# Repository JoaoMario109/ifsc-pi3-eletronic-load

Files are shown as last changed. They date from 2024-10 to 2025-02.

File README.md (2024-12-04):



<!-- PROJECT LOGO -->
<br />
<div align="center">
  <a href="https://github.com/JoaoMario109/ifsc-pi3-eletronic-load">
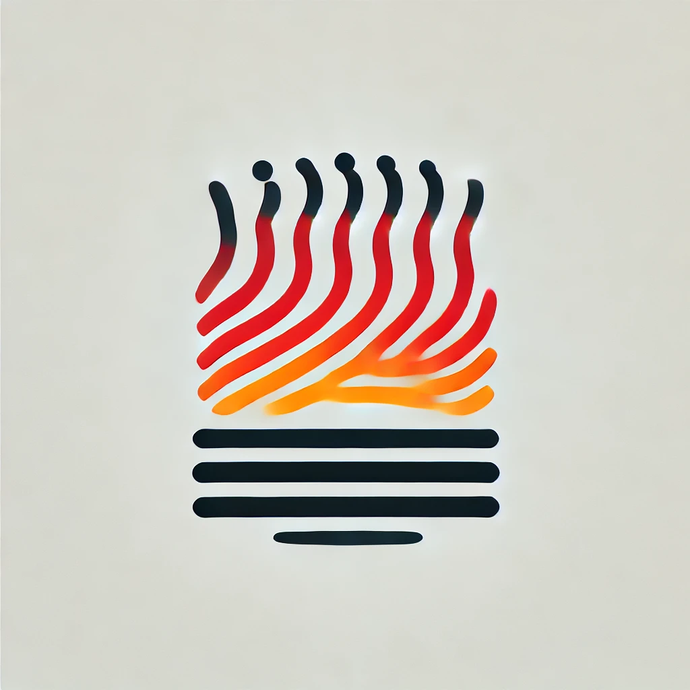
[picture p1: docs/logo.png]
Project Logo
    
  </a>

  <h3 align="center">Simple Electronic Load</h3>

  <p align="center">
    <br />
    <br />
    <a href="https://github.com/JoaoMario109/ifsc-pi3-eletronic-load/issues">Report Bug</a>
    ·
    <a href="https://github.com/JoaoMario109/ifsc-pi3-eletronic-load/issues">Request Feature</a>
  </p>
</div>

<!-- TABLE OF CONTENTS -->
<details>
  <summary>Table of Contents</summary>
  <ol>
    <li>
      <a href="#about-the-project">About The Project</a>
      <ul>
        <li><a href="#about-the-project-overview">Overview</a></li>
      </ul>
    </li>
    <li>
      <a href="#license">License</a>
    </li>
    <li>
      <a href="#contact">Contacts</a>
    </li>
  </ol>
</details>

<!-- ABOUT THE PROJECT -->

## About The Project

This project is the implementation of a simple electronic load with WiFi integration and the ability to operate using custom waveforms. It forms part of (PI3) for the Electronics Engineering course at IFSC, Campus Florianópolis.

### Overview

The electronic load is designed to handle up to 100W of power and supports four different operating modes: constant current, constant power, constant resistance, and constant voltage. Additionally, it can execute custom waveforms uploaded via its various communication interfaces.

The load is divided into three key modules:
1. **Power Module** – Contains the hardware components responsible for handling the load, such as the power transistors and other essential elements.
2. **Control Module** – Manages the desired operating mode and ensures the system maintains the appropriate levels of current, voltage, or resistance.
3. **Communication Module** – Facilitates interaction between the user and the device via WiFi, USB, or other interfaces, and stores custom waveforms on an SD card for future use.

The device can be accessed through its control panel, WiFi, or USB interface, and its communication capabilities can easily be expanded. Any compatible interface can be connected to the main I2C bus using an SCPI-like protocol.

<p align="right">(<a href="#top">back to top</a>)</p>

<!-- LICENSE -->

## License

Distributed under the MIT License. See [LICENSE](LICENSE) for more information.

<p align="right">(<a href="#top">back to top</a>)</p>

<hr />

<!-- CONTACT -->

## Contact

Alejo Perdomo Milar [alejo.pm@aluno.ifsc.edu.br](alejo.pm@aluno.ifsc.edu.br)\
João Mário Carnieletto Izoton Lago [joao.mcil2003@aluno.ifsc.edu.br](joao.mcil2003@aluno.ifsc.edu.br)\
Paulo Cezar Ventura Junior [paulo.cvj@aluno.ifsc.edu.br](paulo.cvj@aluno.ifsc.edu.br)

Project Link: [https://github.com/JoaoMario109/ifsc-pi3-eletronic-load](https://github.com/JoaoMario109/ifsc-pi3-eletronic-load)

<p align="right">(<a href="#top">back to top</a>)</p>

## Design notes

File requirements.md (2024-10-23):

| **Absolute Maximum Values** | **Maximum Value** | **Unit** |
| --- | --- | --- |
| **Maximum Power** | 100 | W |
| **Maximum Current** | 10 | A |
| **Maximum Voltage** | 70 | V |
| **Maximum Temperature** | 100 | °C |

| **Control Parameters** | **Range** | **Unit** |
| --- | --- | --- |
| **Constant Power** | 0.1 ~ 100¹ | W |
| **Constant Current** | 0.2 ~ 10 | A |
| **Constant Voltage** | 2 ~ 70 | V |
| **Constant Resistance** | 3 ~ 500¹ | Ω |
| **Update Frequency** | 2 | Hz |
| **Current Resolution** | 0.1 | A |
| **Voltage Resolution** | 0.1 | V |
| **Over Power Protection** | 100 | W |
| **Over Voltage Protection** | 70 | V |
| **Over Current Protection** | 10 | A |
| **Over Temperature Protection** | 90 | °C |

¹ Depends on the input voltage and current.

| **Communication Protocols** | **Interface** |
| --- | --- |
| WebSocket | WiFi |
| SD card | SD card |
| I²C | Wired connection |

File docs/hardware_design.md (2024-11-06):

# Seção Analógica

## Correção de Offset

Os diodos na seção de correção de offset têm a função de compensar o fato de que o amplificador LM324 não é do tipo rail-to-rail, ou seja, ele não consegue atingir os 12V necessários para despolarizar completamente o transistor PNP Q2. Assim, foram utilizados diodos em série para que a queda de tensão neles crie um offset no emissor, garantindo uma operação correta.

## Controle Analógico

O controle analógico da carga eletrônica é composto por duas etapas principais:

### 1. Inversor de Sinal

Esta etapa consiste em um inversor para compensar o fato de que o driver com transistor PNP inverte o sinal. Pela natureza do circuito, com 12V não haverá passagem de corrente pelo transistor PNP, enquanto com 0V haverá a corrente máxima. Após a inversão, com 0V não haverá corrente, e o aumento da corrente será proporcional à tensão de entrada.

### 2. Controlador PID Analógico

A segunda etapa é um controlador PID analógico feito com um amplificador operacional (ampop). Esse controlador é interessante porque, caso seja necessário desativá-lo para utilizar apenas o controle digital, basta colocar um curto em R14 e C6.

O cálculo do controlador foi feito através de um método empírico de sucessivas aproximações, onde, utilizando o LTSpice, foram ajustados os valores de capacitância e resistência até atingir o comportamento desejado. É importante ressaltar que sempre há uma diferença entre simulação e prática; portanto, quando implementado em bancada, será realizado um ajuste fino dos componentes.

| Componente | Descrição |
|---|---|
| **Capacitor C3** | Aumentar a capacitância de C3 reduz o tempo de subida (rise time), mas também aumenta o fenômeno de ringing. |
| **Resistor R10** | Reduzir a resistência de R10 aumenta a velocidade do circuito, mas também eleva o ringing. |
| **Capacitor C6** | Controla a velocidade de resposta do controlador. Quanto maior a capacitância, mais lenta será a resposta. |

Os resistores em série com os capacitores têm uma função equivalente à variação direta da capacitância dos capacitores associados.

### Valores Encontrados

| Componente | Valor |
|---|---|
| R14 | 330Ω |
| C6 | 10nF |
| R10 | 720Ω |
| C3 | 100nF |
| R13 | 5kΩ |
| R11 | 1kΩ |

### Simulação

<div style="text-align: center;">
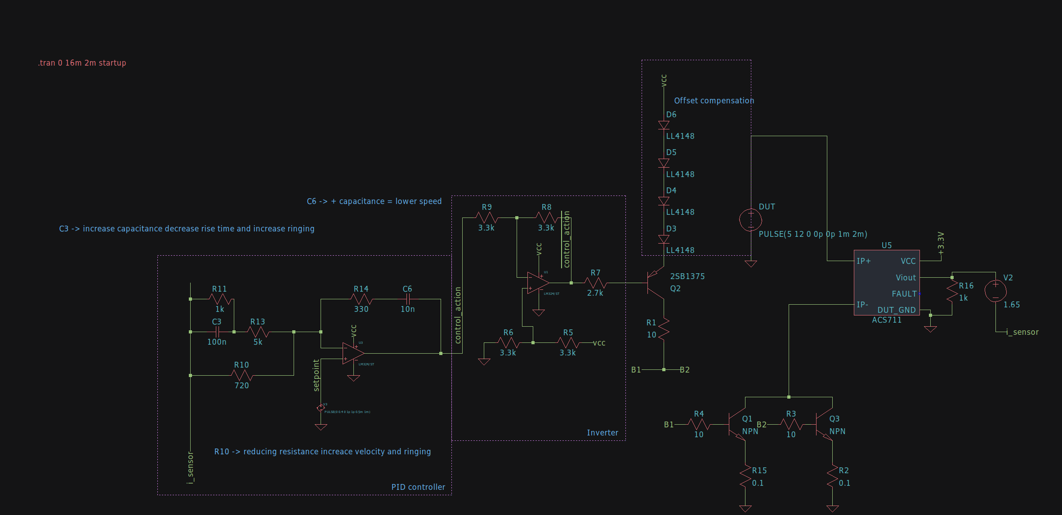
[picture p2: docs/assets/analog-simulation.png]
Simulação do Controlador PID Analógico
	
</div>

<div style="text-align: center;">
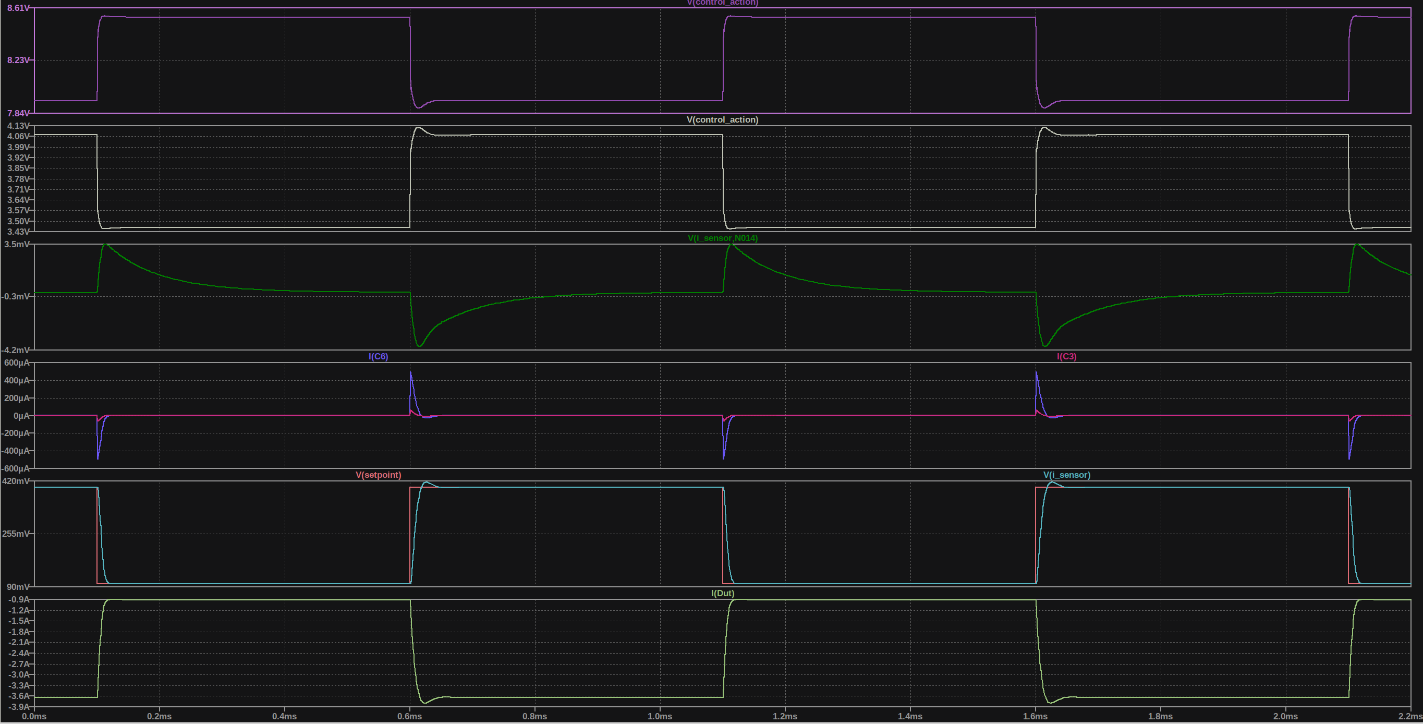
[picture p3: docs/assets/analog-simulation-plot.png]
Simulação do Controlador PID Analógico Plot
	
</div>

### Observações

A resposta do controlador PID analógico é satisfatória para o projeto, tendo um leve overshoot e settling time aceitável. Ainda assim, é importante ressaltar que a implementação prática pode apresentar diferenças em relação à simulação, e ajustes finos podem ser necessários.

---

## Sensor de Tensão

A configuração do sensor de tensão consiste em um divisor de tensão simétrico com redução de modo comum, conectado a um amplificador operacional em modo diferencial.

### Divisor de Tensão

O divisor de tensão é composto por três etapas acopladas:

1. **Divisor de Tensão de Modo Comum**: Resistores conectados ao GND, em conjunto com resistores em série com a entrada, atuam como divisor de tensão para o modo comum.
2. **Divisor de Tensão Diferencial**: Um resistor que conecta os resistores do divisor em série com a entrada funciona como um divisor diferencial, configurado de forma simétrica para maximizar a redução de ruído.

Para o cálculo dos valores desses divisores, foi utilizado o método empírico de sucessivas aproximações.

### Amplificador Operacional em Modo Diferencial

O amplificador operacional diferencial é usado nesta configuração porque a entrada terá um offset de tensão devido às quedas de tensão nos fios e trilhas. O ganho foi ajustado para que, com uma entrada de 120V no divisor de tensão, a saída forneça 3.3V, aproveitando todo o range do ADC.

### Filtros

Existem três etapas de filtro passa-baixa no circuito:

- **Entrada (2 filtros)**: Reduzem o ruído de modo comum e diferencial.
- **Saída (1 filtro)**: Reduz o ruído de saída do amplificador operacional.

Todos os filtros foram calculados para ter uma frequência de corte aproximada de 1kHz.

### Proteções

O circuito conta com proteções contra sobretensão e tensão reversa, tanto na entrada quanto na saída. A proteção de sobretensão é feita por diodos TVS.

### Valores Encontrados

| Componente | Valor |
|---|---|
| R5, R6 | 50kΩ |
| R7, R8, R9 | 1kΩ |
| C2, C4 | 100nF |
| C3 | 10nF |
| R10 | 500Ω |
| C1 | 1uF |

### Simulação

<div style="text-align: center;">
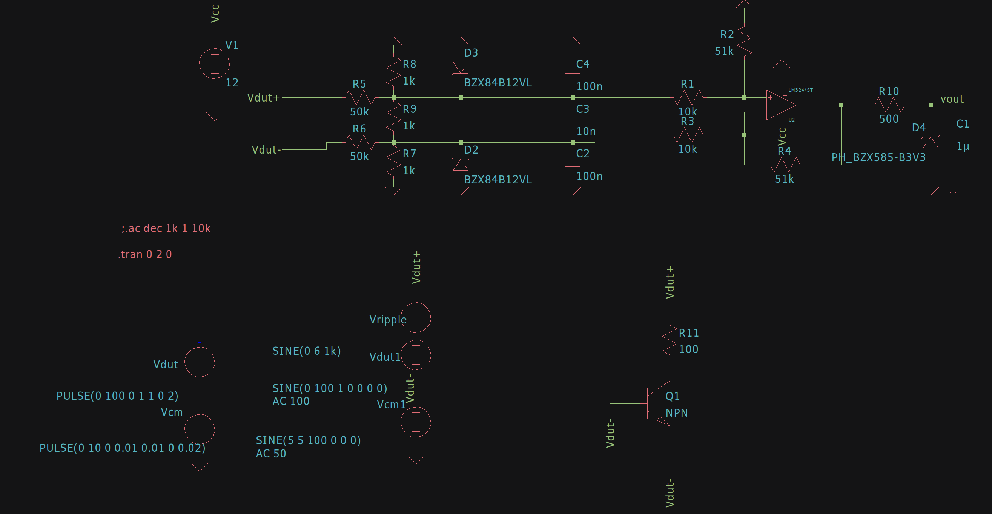
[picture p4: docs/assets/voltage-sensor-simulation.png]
Simulação do Sensor de Tensão
	
</div>

<div style="text-align: center;">
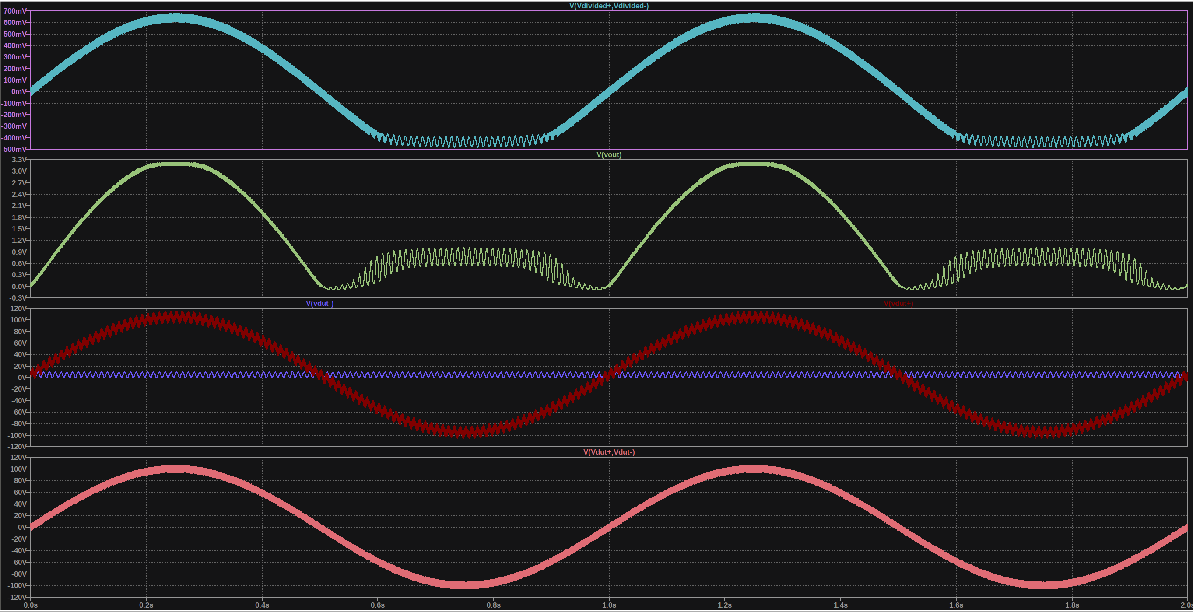
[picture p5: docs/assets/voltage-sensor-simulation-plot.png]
Simulação do Sensor de Tensão Plot
	
</div>

---

# Seção de Potência

## Polarização do Transistor de Potência e Driver

Para determinar os valores dos resistores de base dos transistores de potência, foi utilizado o método de sucessivas aproximações, buscando um ponto de operação onde o transistor tenha corrente de base suficiente para entrar em saturação.

### Valores Encontrados

| Componente | Valor |
|---|---|
| Resistor da base | 20Ω |
| Resistor da base do driver | 2.2kΩ |
| Resistor do emissor | 0.1Ω  |

---

## Cálculo da Resistência Térmica Máxima do Dissipador

Para determinar a resistência térmica máxima do dissipador necessário para dissipar uma potência total de 100W distribuída entre dois transistores, com aplicação direta de pasta térmica, foram consideradas as seguintes especificações:

| Especificação | Valor |
|---|---|
| Resistência térmica junction-to-case (Rθjc) | 1.25 °C/W |
| Temperatura ambiente máxima | 30 °C |
| Temperatura máxima de operação | 120 °C |

### Cálculo

1. **Cálculo do aumento de temperatura permitido ($\Delta T$)**:
   $$
   \Delta T = T_{max} - T_{amb} = 120 \,°C - 30 \,°C = 90 \,°C
   $$

2. **Distribuição da Potência**: Cada transistor dissipará 50W.

3. **Resistência Térmica Junction-to-Case Total**:
   $$
   R_{\theta jc} \times P = 1.25 \,°C/W \times 50 \,W = 62.5 \,°C
   $$

4. **Resistência Térmica Necessária para o Dissipador ($R_{\theta sa}$)**:
   $$
   R_{\theta sa} = \frac{\Delta T - (R_{\theta jc} \times P)}{P_{total}} = \frac{27.5 \,°C}{100 \,W} = 0.275 \,°C/W
   $$

Portanto, para manter a temperatura dos transistores abaixo de 120 °C, a resistência térmica máxima do dissipador deve ser **0.275 °C/W**.

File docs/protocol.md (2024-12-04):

# SCPI-like Protocol

## I2C Bus Overview

Devices controlling the load must connect to the load's I2C bus to send commands. The protocol supports hierarchical parsing with registers and sub-registers to interact with the load server and HMI server.

### I2C Addresses

- **Load Server:** 0xA  
  Responsible for managing active control of power and analog systems. This runs on the STM32 in the load module.  
- **HMI Server:** 0x5  
  Manages operations on the SD card, load configuration, and streaming functionalities. This runs on the ESP32 in the front panel.

---

## Protocol Specifications for I2C Communication

### Command Format

The protocol uses a structured command format, represented as:  
**C:R:S:VV**  

- **C:** Command type (0x0 for query, 0x1 for set)
- **R:** Register (defines the resource or mode being accessed)
- **S:** Sub-register (specific sub-resource or parameter)
- **VV:** Value (2 bytes, applicable for set operations)

### Supported Commands

#### Identification (ID)
- **Query ID**:  
  Command: `0x0:0x0:0x0`  
  Returns the identification string of the load module.  

#### Input Control (IN)
- **Disable Input**:  
  Command: `0x1:0x1:0x0:0x0`  
  Disables the input (output terminals).  
- **Enable Input**:  
  Command: `0x1:0x1:0x0:0x1`  
  Enables the input (output terminals).  
- **Query Input State**:  
  Command: `0x0:0x1:0x0`  
  Returns whether the input is currently enabled or disabled.  

#### Operating Modes (MD)
- **Query Mode**:  
  Command: `0x0:0x2:0x0`  
  Returns the currently selected operating mode.  
- **Set Mode to Constant Current (CC)**:  
  Command: `0x1:0x2:0x1`  
- **Set Mode to Constant Voltage (CV)**:  
  Command: `0x1:0x2:0x2`  
- **Set Mode to Constant Resistance (CR)**:  
  Command: `0x1:0x2:0x3`  
- **Set Mode to Constant Power (CP)**:  
  Command: `0x1:0x2:0x4`  

#### Levels (LV)
- **Query Level**:  
  Command: `0x0:0x3`  
  Queries the current level for the specified sub-register.  
- **Set Current Level**:  
  Command: `0x1:0x3:0x1:VV` (Value in amperes)  
- **Set Voltage Level**:  
  Command: `0x1:0x3:0x2:VV` (Value in volts)  
- **Set Resistance Level**:  
  Command: `0x1:0x3:0x3:VV` (Value in ohms)  
- **Set Power Level**:  
  Command: `0x1:0x3:0x4:VV` (Value in watts)  

#### Status (ST)
- **Query Status**:  
  Command: `0x0:0x4:0x0`  
  Returns a structured response with the following fields:  
  - **Byte 1:** Input state (0 or 1)  
  - **Byte 2:** Current mode (CC, CV, CR, CP)  
  - **Bytes 3-4:** Current set current value  
  - **Bytes 5-6:** Current set voltage value  
  - **Bytes 7-8:** Current set resistance value  
  - **Bytes 9-10:** Current set power value  
  - **Bytes 11-12:** Measured current value  
  - **Bytes 13-14:** Measured voltage value  

### Commands
| Command |  Value | Description |
|---|---|---|
| Query | 0x0 | Query the value of a register |
| Set | 0x1 | Set the value of a register |

### Registers

| Mode | Register | Description |
|---|---|---|
| ID  | 0x0 | Constant Current |
| IN  | 0x1 | Input |
| MD  | 0x2 | Mode |
| LV  | 0x3 | Levels |
| ST  | 0x4 | Status |

### Sub-Registers

| Mode | Sub-Register | Description |
|---|---|---|
| __  | 0x0 | General |
| CC  | 0x0 | Current |
| CV  | 0x1 | Voltage |
| CR  | 0x2 | Resistance |
| CP  | 0x3 | Power |

## HMI Protocol (HMI Server)

### Resource Codes

- **ID** Identification
- **LK** Panel Locking
- **ST** Streamer module
- **CX** Set File Descriptor
- **LS** SD Read Operation
- **WT** SD Write Operation

### Identification

- **ID?** Queries the panel module for its identification string.

### Panel Locking

- **LK?** Queries whether the front panel is currently locked (user interaction disabled) or unlocked (user interaction enabled).
- **LK 0** Unlocks the front panel, preventing user interaction.
- **LK 1** Locks the front panel, allowing user interaction.

### SD Card File Operations

#### Listing available files

- **LS 0** Queries files in SD card `streams` directory from page zero, each page contains 10 files.

#### Selecting a file descriptor

- **CX?** Queries the current file descriptor.
- **CX <name 20 chars>.st** Sets the file descriptor to the specified file. The file descriptor is used in subsequent operations to refer to the file.
- **CX 0** Resets the file descriptor to zero.

#### Write operations (Set file descriptor before writing, if file descriptor does not exist, it will be created)

- **WT** This will clean current file in file descriptor.
- **WT <cmd>** This will write the data to the file in file descriptor, data can be any of valid commands in protocol.

#### Streamer module

- **ST?** Will return 1 if streamer module is streaming data, 0 otherwise.
- **ST 0** Will stop the streamer module.
- **ST 1** Will start the streamer module using the file descriptor as the source.

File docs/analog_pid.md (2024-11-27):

## Ajuste do Controlador Analógico

Para realizar o ajuste (tuning) do controlador analógico, foram colocados dois trimpots nos resistores R13 e R10, conforme mostrado na figura abaixo:

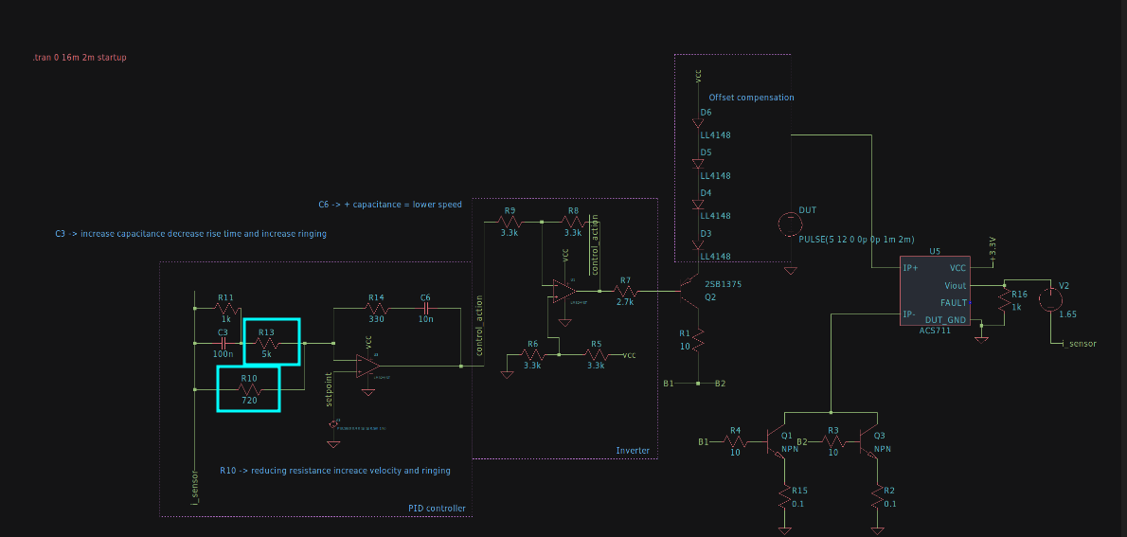
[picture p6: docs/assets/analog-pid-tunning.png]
Ajuste PID Analógico


O valor de R10 foi ajustado inicialmente para obter a resposta mais rápida possível com uma leve oscilação. Em seguida, o valor de R13 foi modificado para reduzir essa oscilação.

### Respostas do Controlador no Osciloscópio

Abaixo estão algumas capturas do osciloscópio mostrando a resposta do controlador analógico com diferentes ajustes dos trimpots:

- Resposta com tempo de subida rápido mas com maior oscilação:
  
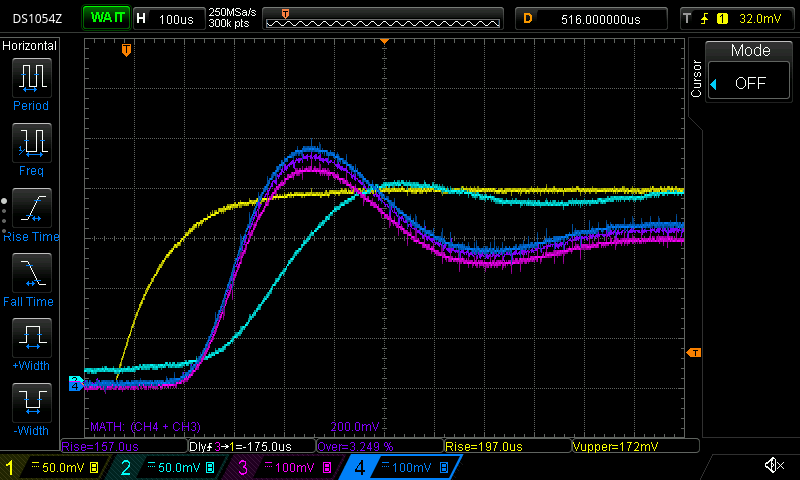
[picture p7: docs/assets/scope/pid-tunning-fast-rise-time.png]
Osciloscópio PID Rápido
  

- Resposta com tempo de subida médio e oscilação moderada:
  
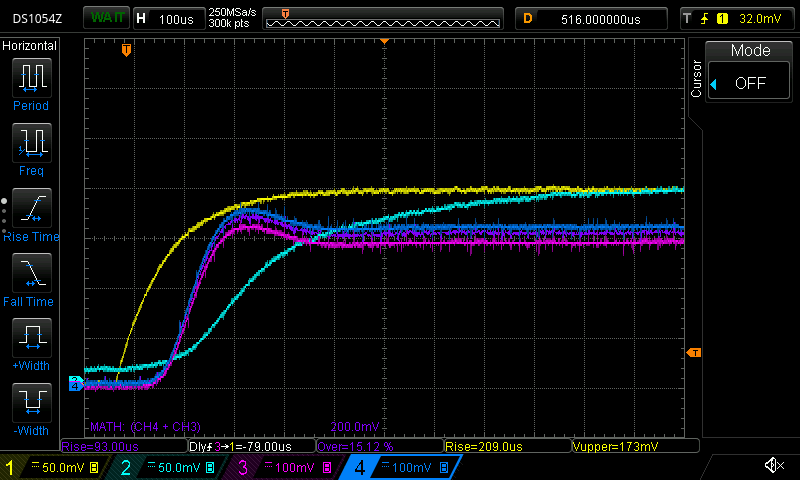
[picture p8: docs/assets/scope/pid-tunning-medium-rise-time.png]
Osciloscópio PID Médio
  

- Resposta com tempo de subida lento e oscilação mínima:
  
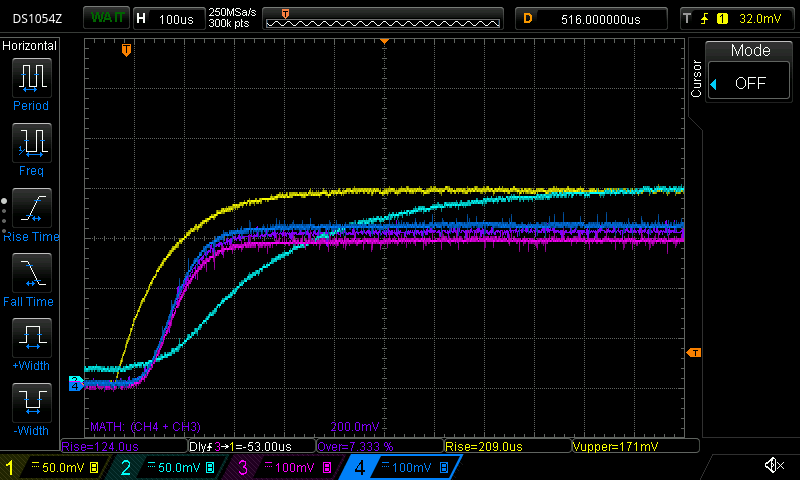
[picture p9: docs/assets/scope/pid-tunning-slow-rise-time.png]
Osciloscópio PID Lento
  

**Legenda dos canais no osciloscópio:**
- Canal amarelo: setpoint
- Canal azul claro: saída do sensor de corrente
- Canal azul escuro e roxo: corrente em cada transistor

A melhor resposta foi obtida com os valores de **R10 = 2k7** e **R13 = 250R**, resultando em um atraso de resposta de 97 µs e um tempo de subida de 111 µs, significativamente mais rápido que o desejado (2 Hz).

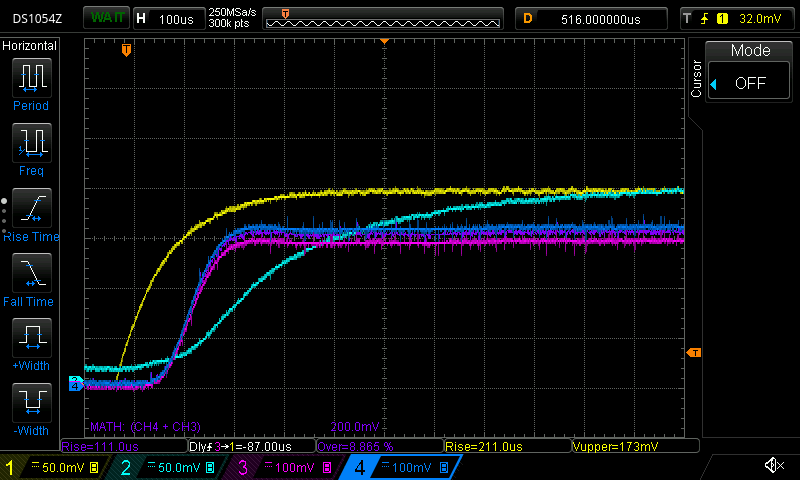
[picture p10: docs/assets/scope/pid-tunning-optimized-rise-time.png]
Osciloscópio PID Otimizado


### Resposta do Controlador em Condições de Estresse

Abaixo estão as capturas do osciloscópio com o controlador analógico sob estresse, usando a frequência máxima do DAC para gerar o setpoint.

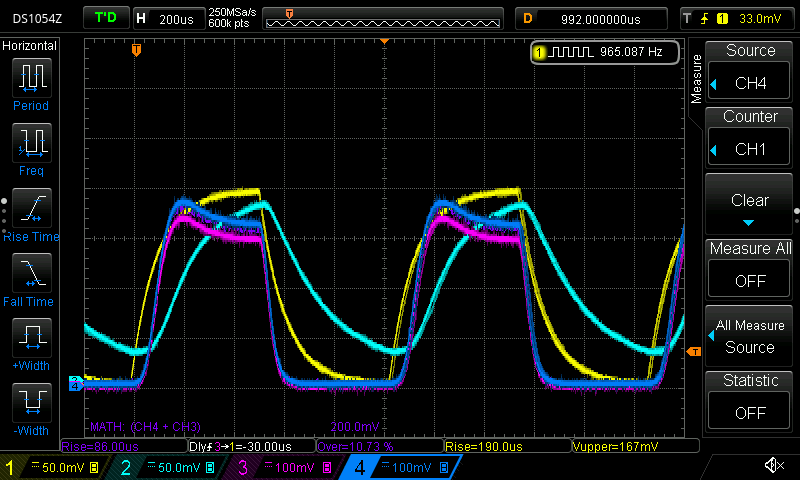
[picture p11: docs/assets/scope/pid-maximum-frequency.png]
Osciloscópio PID Frequência Máxima


Como pode ser visto na imagem acima, o controlador consegue manter aproximadamente **955 Hz** de forma satisfatória.

Abaixo está a resposta do controlador analógico operando a 250 Hz.

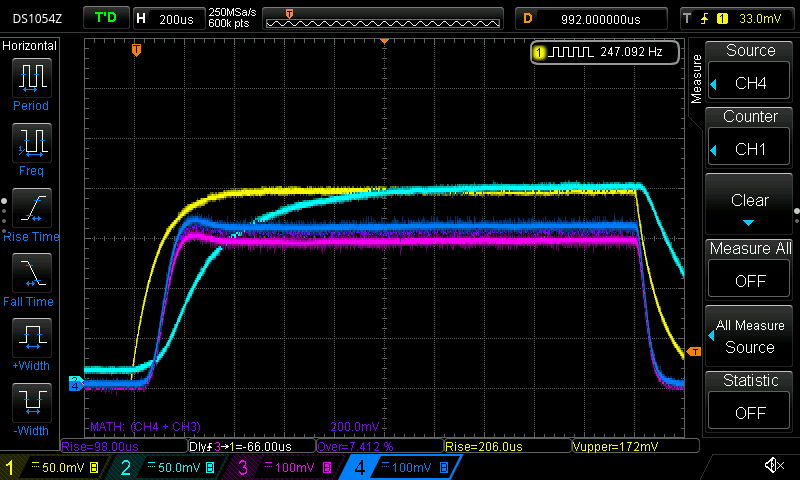
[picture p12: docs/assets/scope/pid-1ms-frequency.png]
Osciloscópio PID 250Hz


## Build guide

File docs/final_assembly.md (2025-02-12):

# Montagem Final

## Introdução
Nesta etapa final, toda a estrutura de hardware foi consolidada com foco na comunicação entre a placa de carga (Load) e o painel de controle (Panel). Devido a um bug em modo **slave** descrito na *errata* do STM32F10xx8/STM32F10xxB, optou-se por realizar a comunicação via **UART**, garantindo estabilidade e confiabilidade no envio e recebimento de dados.

## Comunicação via UART
- **Motivo da Mudança**: O microcontrolador STM32 apresentou inconsistências no protocolo I2C em modo *slave*, reportadas na errata *STM32F10xx8 STM32F10xxB Errata Sheet*.
- **Estrutura de Dados**: A transmissão e recepção via UART seguem um protocolo binário com o formato:
  - `[MAGIC_WORD, DATA, CRC]`
  - A seção `DATA` contém sempre a mesma estrutura para o TX e outra para o RX, porém com finalidades diferentes:
    - **Load -> Panel**: Envia leituras de tensão, corrente, temperatura e demais medições do sistema.
    - **Panel -> Load**: Envia comandos de configuração (modo de operação, valores de corrente, tensão, etc.) e de controle (habilitar/desabilitar carga).
- **Implementação**: A comunicação UART se dá em nível lógico compatível com o microcontrolador, sendo necessário um cabo com conectores KK para interligar a placa da carga e o painel.

## Montagem dos Transistores no Dissipador
Para lidar com a dissipação de calor gerada pelos transistores de potência, foi montado um *stack* de refrigeração:
1. **Transistor**: Fixado ao dissipador por meio de uma estrutura de aço (frame) e parafusos.
2. **Sensor de Temperatura**: Entre o frame de aço e o transistor, posiciona-se a placa do sensor de temperatura, permitindo leituras próximas ao componente principal de aquecimento.
3. **Dissipador com Cooler**: O dissipador utilizado é um comercial de CPU, dotado de ventilador para refrigeração ativa. Ele é conectado à placa da carga, que controla a velocidade do cooler conforme a temperatura.

Dissipador
> *Figura 1: Ilustra a disposição dos componentes no *stack* térmico.*

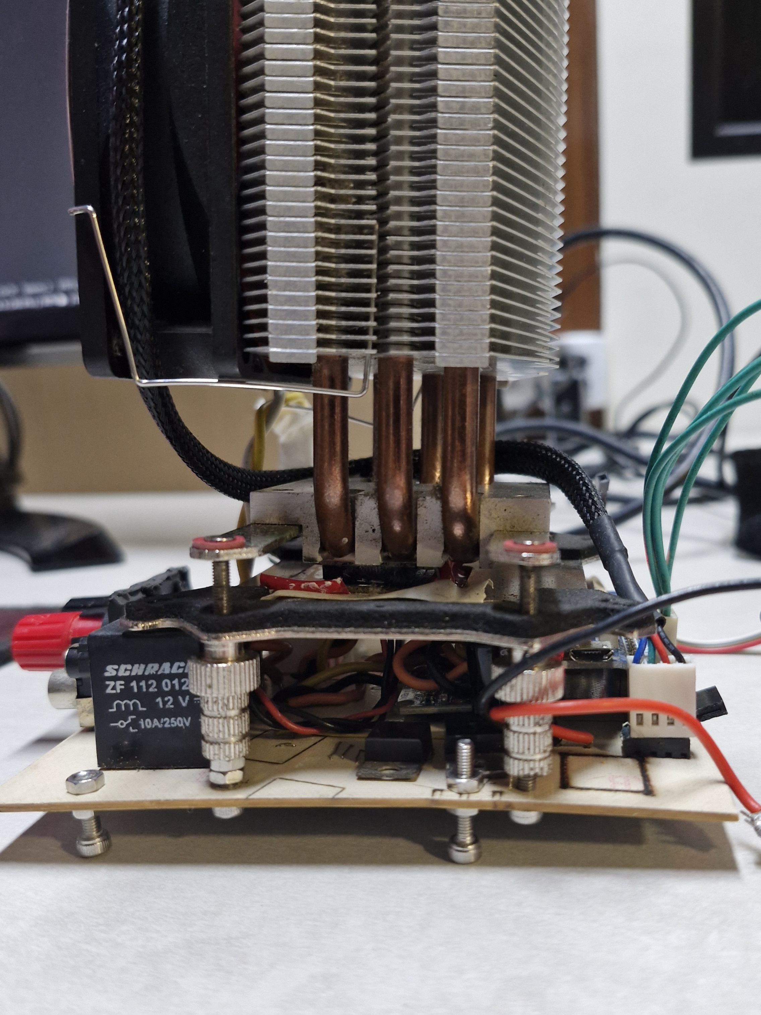
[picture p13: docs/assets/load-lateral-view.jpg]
Dissipador Real

> *Figura 2: Ilustra a disposição dos componentes no *stack* térmico* na foto real.*

## Fixação na Placa de Controle
- A pilha de dissipador + transistores + sensor de temperatura é aparafusada à placa de controle, garantindo estabilidade mecânica e facilidade de manutenção.
- Parafusos e porcas adicionais fixam o conjunto de forma segura, evitando vibrações ou desalinhamentos que poderiam prejudicar a medição de temperatura ou a eficiência do dissipador.

## Conectores Banana
Foram adicionados **conectores banana** nos pontos de entrada/saída de corrente e tensão. Isso facilita a conexão rápida e segura de cabos de teste, além de permitir medições e mudanças de bancada sem a necessidade de soluções improvisadas.

## Cabo de Conexão do Painel
- A comunicação entre a placa da carga e o painel se dá por um cabo com dois conectores KK, por onde são levados **alimentação** e **dados** (UART).
- Esse design modular permite desconectar o painel com facilidade. Dessa forma, é possível:
  1. Conectar um **conversor USB-Serial** diretamente na placa de carga para realizar testes, enviar firmware ou receber dados via PC.
  2. Utilizar a **SDK em Python** ou a **UI Python** para monitoramento e controle do sistema.

## Montagem Final

A seguir são apresentadas imagens da montagem final do sistema, com destaque para a integração entre a placa de carga e o painel de controle.

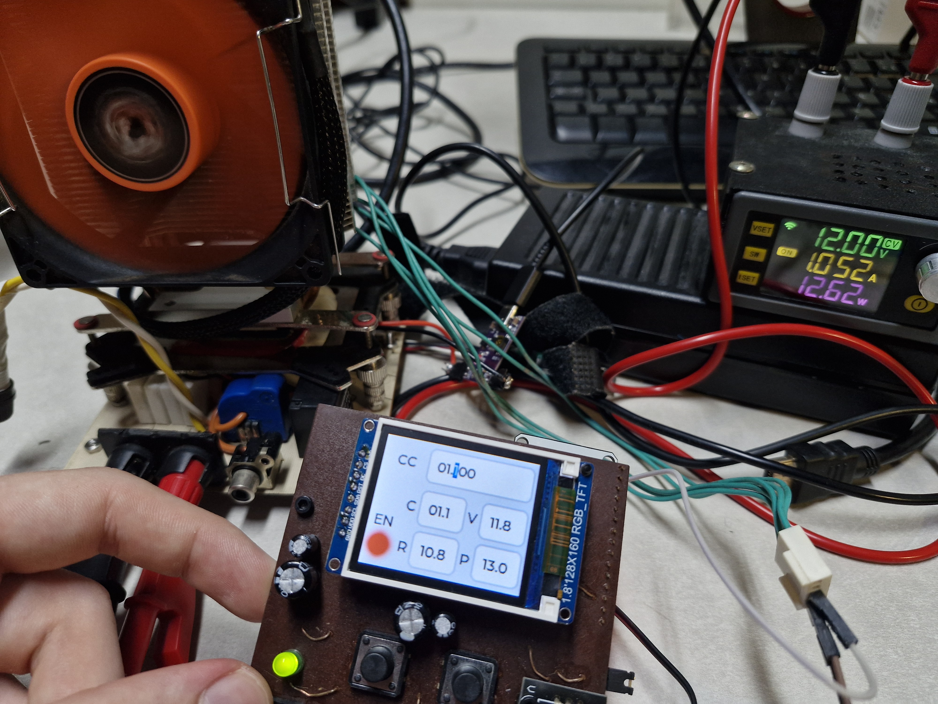
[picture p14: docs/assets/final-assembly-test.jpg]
Montagem Final

> *Figura 3: Ilustra um teste real da carga sendo modificada pelo painel de controle*

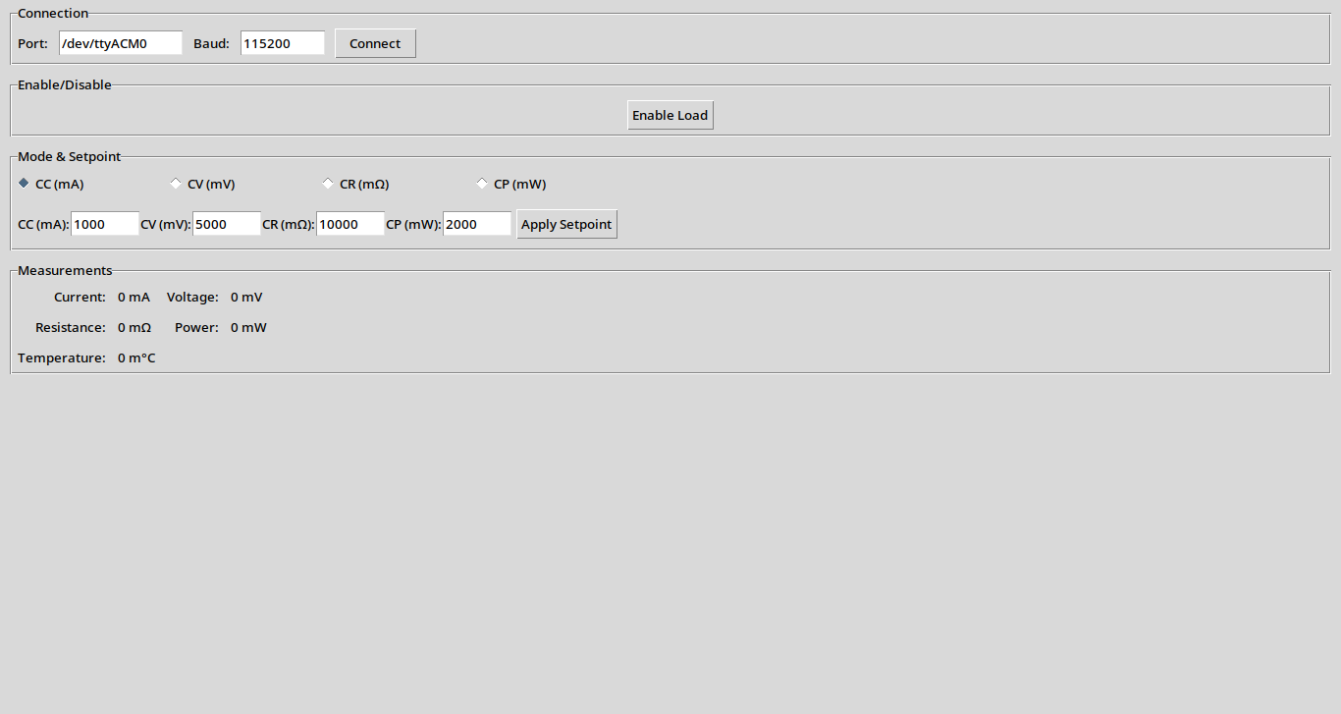
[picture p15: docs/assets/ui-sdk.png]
UI Python

> *Figura 4: Ilustra a UI de controle via adaptador USB/Serial*

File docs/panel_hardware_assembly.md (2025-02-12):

# Montagem do Painel de Controle

## Introdução
O painel de controle é responsável por enviar comandos à carga por meio do protocolo UART. Ele conta com um display TFT ST7735 de 160x128, cinco botões (quatro para seleção de modos – CC, CV, CR, CP – e um para **enable**), além de um encoder para ajuste de valores e um botão embutido no encoder para alternar **cursor/menu**.

Este documento descreve o processo de fabricação e montagem do painel, incluindo a confecção da placa por corrosão química, a solda de componentes THT e SMD, bem como as adaptações necessárias para o correto funcionamento em UART.

## Metodologia de Montagem

### Confecção da PCB
- **Método de Transferência Térmica:** Foi utilizada a impressão do layout em papel *glossy* e, em seguida, a transferência para a placa virgem por meio de uma prensa térmica.
- **Corrosão com Percloreto de Ferro:** Após a transferência do layout, a placa foi mergulhada em percloreto de ferro para corrosão das áreas expostas de cobre, formando as trilhas.
- **Limpeza e Acabamento:** Concluída a corrosão, foi feita a limpeza química para remoção dos resíduos de percloreto, seguida de furação (nos furos de THT) e preparação para solda.

### Montagem dos Componentes
1. **Solda de SMD:** Os componentes SMD foram soldados primeiramente.
2. **Solda de THT:** Posteriormente, foram soldados os componentes de montagem radial ou axial (THT), como conectores, botões, soquetes e o encoder.

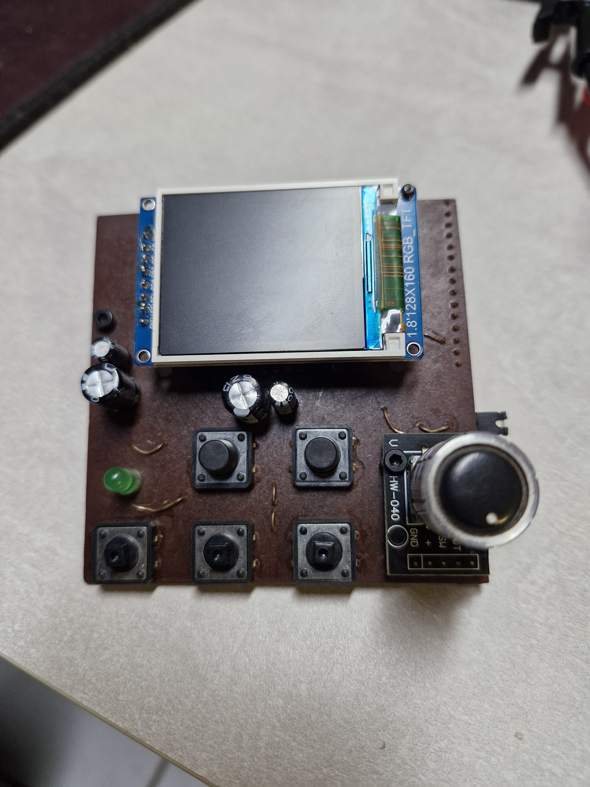
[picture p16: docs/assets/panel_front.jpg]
Panel Front

> *Figura 1: Vista frontal do Painel de Controle, mostrando o display e os botões.*

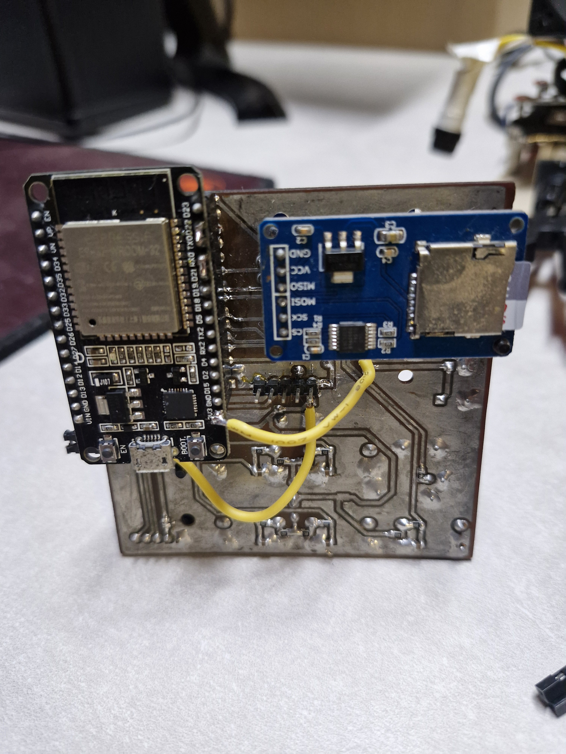
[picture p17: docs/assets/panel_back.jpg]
Panel Back

> *Figura 2: Vista traseira do Painel de Controle, onde é possível observar o ESP e os jumpers adicionados.*

## Testes

### Alimentação e Conectividade
- Antes de energizar o painel, foram verificadas continuidades e possíveis curtos em trilhas e componentes sensíveis.
- Alimentou-se o circuito de forma gradual, monitorando a fonte de alimentação e checando se o display inicializava corretamente.

### Comunicação UART
- Após constatar que o painel precisa se comunicar com a carga via UART (ao invés de I2C), a adaptação dos pinos foi realizada.
- Fez-se a leitura dos dados transmitidos pelo microcontrolador com auxílio de um conversor USB-UART, confirmando a troca de informações entre painel e carga.

### Funcionamento dos Botões e Encoder
- Os cinco botões (quatro de modo e um de enable) foram testados para garantir a correta detecção de cada evento (pressionado/solto).
- O encoder foi girado em ambos os sentidos, e seu botão foi pressionado para confirmar o seu funcionamento.

## Ajustes e Modificações Realizados

1. **Mudança de Pinos (I2C para UART):**
   - Foi necessário soldar um *jumper* do **GPIO1** para o **GPIO22** e do **GPIO21** para o **GPIO3**, convertendo a função de I2C para UART é possivel observar na figura 2.
     - *Justificativa:* Esses pinos, originalmente reservados para o barramento I2C, precisaram ser remapeados para UART a fim de estabelecer a comunicação com a placa de carga.

2. **Jumper para Botões:**
   - Criou-se um *jumper* adicional que permite desconectar fisicamente os botões do microcontrolador.
   - *Motivo:* Durante a gravação do firmware no microcontrolador, os botões podem interferir no processo. Deixá-los em aberto garante que a programação seja feita sem conflitos de pinos.

## Conclusão
A confecção do painel de controle por corrosão térmica e o subsequente processo de soldagem THT/SMD resultaram em um módulo funcional para interação com a carga via UART. Os ajustes de pinos (de I2C para UART) e a adição de jumpers para permitir a gravação do microcontrolador foram fundamentais para o sucesso da montagem.

Com esse painel, é possível selecionar os modos de operação (CC, CV, CR, CP), habilitar ou desabilitar a carga e ajustar parâmetros via encoder, tornando o sistema completo para testes e controle de cargas em diferentes cenários de aplicação.

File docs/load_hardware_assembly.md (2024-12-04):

# Montagem da Placa da Carga

## Introdução

A montagem da placa de carga foi realizada como parte do desenvolvimento de um sistema para controle e monitoramento de carga. O processo incluiu a solda de componentes, validação de funcionamento e ajustes no hardware para garantir a precisão e estabilidade do sistema.

## Metodologia de Montagem

A montagem foi guiada pelo **IBOM (Interactive Bill of Materials)** gerado no KiCAD, o que facilitou a identificação e posicionamento correto de cada componente na placa.

O IBOM pode ser localizado [aqui](../hardware/load/output/ibom.html).

### Passos Realizados:
1. Soldagem inicial de todos os componentes, com atenção à polaridade e orientação especificadas no IBOM.
2. Verificação de conexões críticas e continuidade usando ferramentas de medição.
3. Ajustes manuais e correções em componentes conforme necessário.

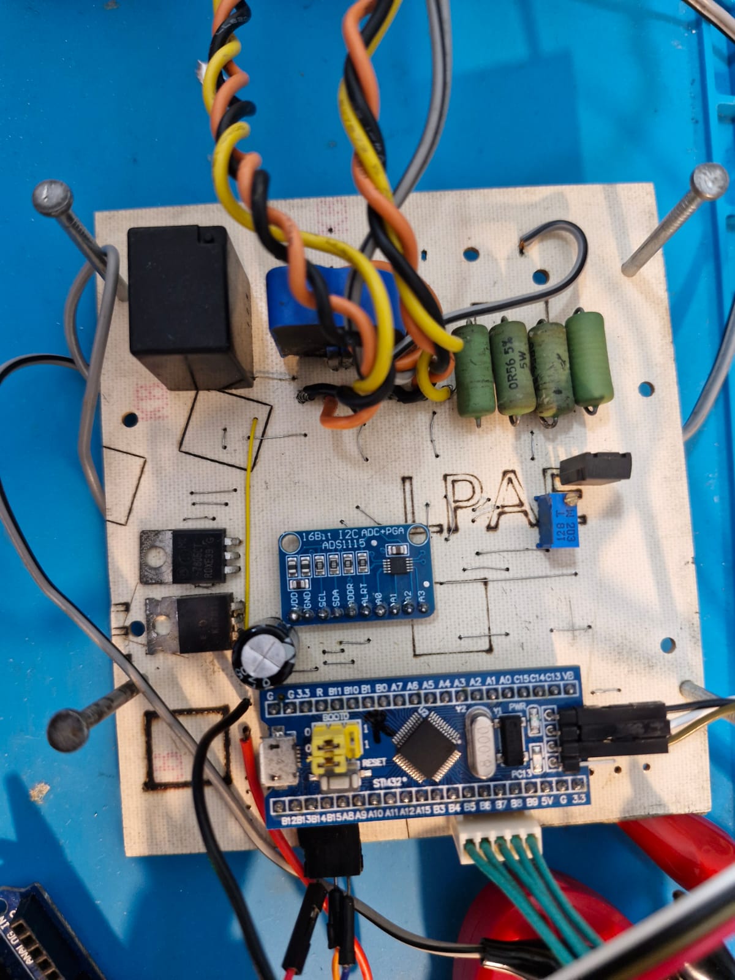
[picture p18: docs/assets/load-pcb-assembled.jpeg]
load-pcb-assembly

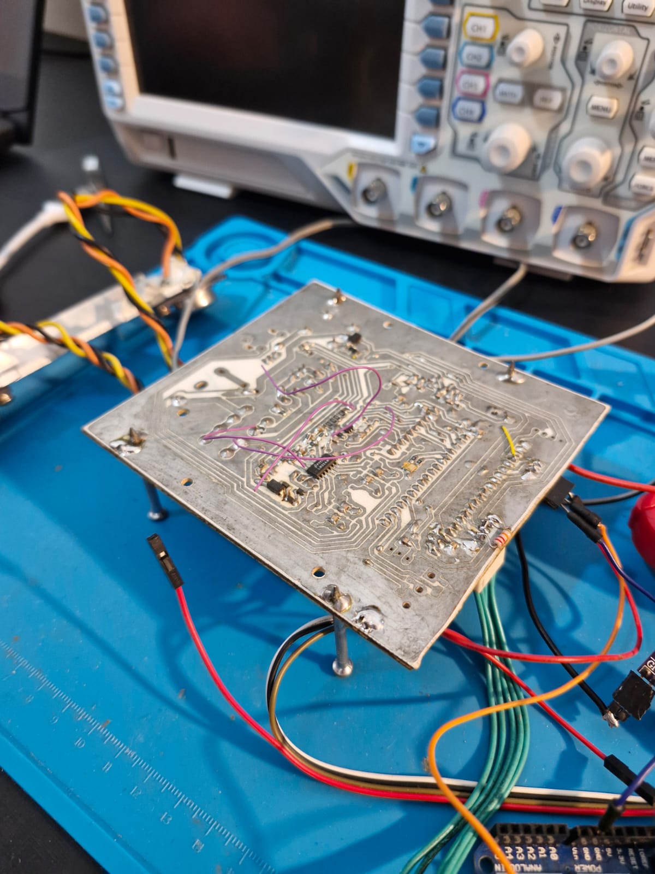
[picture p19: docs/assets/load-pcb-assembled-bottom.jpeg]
load-pcb-assembly-bottom


## Testes

### Verificação da Montagem
- Após soldar todos os componentes, os jumpers foram mantidos desligados para evitar curtos indesejados durante os testes iniciais.
- Alimentação da placa:
  - Sequência de ligação dos jumpers: `input`, `5V`, e `3.3V`.
  - Verificação das tensões em pontos específicos para confirmar o funcionamento dos reguladores.
- Testes dos módulos:
  - **Microcontrolador:** Funcionamento verificado após alimentação.
  - **Sensor de Corrente:** Testado para garantir leituras consistentes.
  - **ADC e DAC:** Validação completa para confirmar a conversão de sinais.

### Tuning do PID Analógico
- Trimpots foram adicionados para ajustar manualmente os ganhos do controlador PID.
- Testes de resposta no osciloscópio foram realizados para otimizar a estabilidade e a eficiência do sistema.

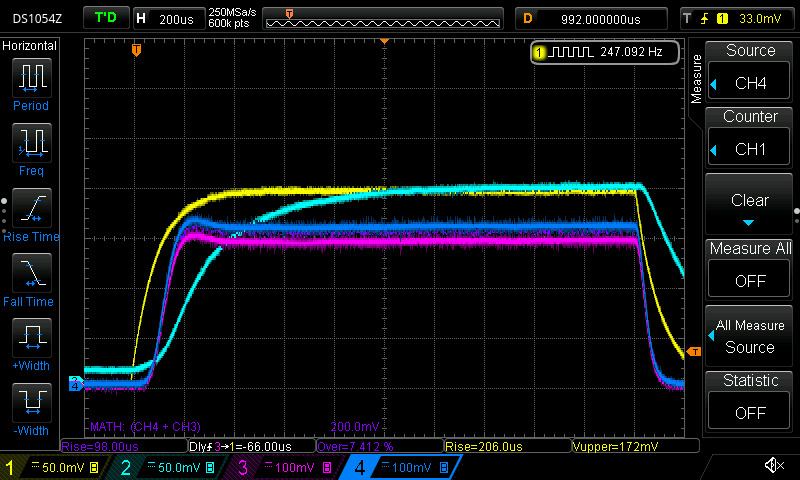
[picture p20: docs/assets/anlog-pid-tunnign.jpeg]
Teste do PID

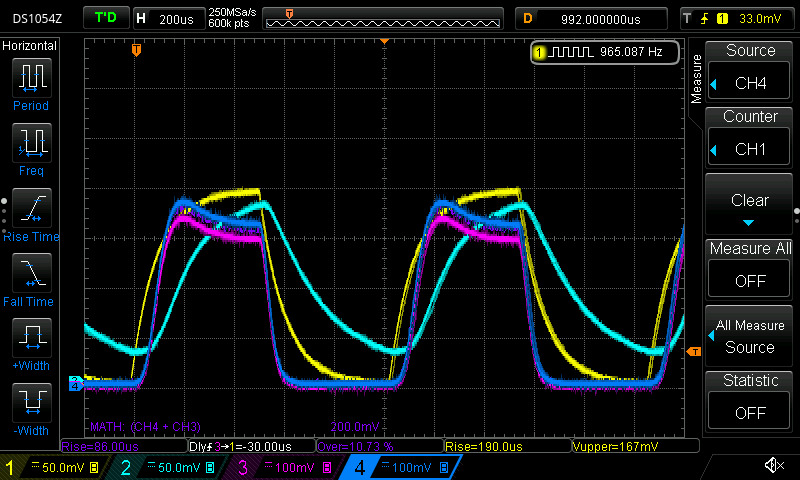
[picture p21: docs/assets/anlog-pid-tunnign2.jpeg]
Teste do PID 2


### Teste de Linearização do ADC
- Realizada uma varredura em passos de 10 mV no DAC.
- Corrente exigida pela carga foi medida com um alicate amperímetro, comparando com os valores obtidos pelo ADC.
- Ajustes realizados usando uma regressão linear, atingindo precisão de 97%.

## Modificações na Placa

Durante o processo, algumas modificações foram necessárias:
1. **Sensor de Corrente:** 
   - O componente na biblioteca do KiCAD estava invertido.
   - Foi necessário cortar a trilha e adicionar um fio para corrigir o sentido.
2. **Relé:** 
   - A trilha de `enable` do relé foi desconectada.
   - Um fio foi adicionado para ligar o `enable` entre o microcontrolador e o transistor de drive.
3. **Estabilização do Transistor:**
   - Resistores de estabilização foram aumentados, melhorando a estabilidade em troca de um leve aumento na tensão mínima de operação.
4. **Transistores de Potência:**
   - Utilizados temporariamente os transistores **2N3773**, devido à indisponibilidade dos projetados.

## Conclusão

A montagem da placa e os testes realizados validaram a funcionalidade básica do sistema. Os ajustes no PID e a linearização do ADC garantiram alta precisão nos resultados, embora algumas melhorias ainda possam ser implementadas nas próximas iterações do projeto.

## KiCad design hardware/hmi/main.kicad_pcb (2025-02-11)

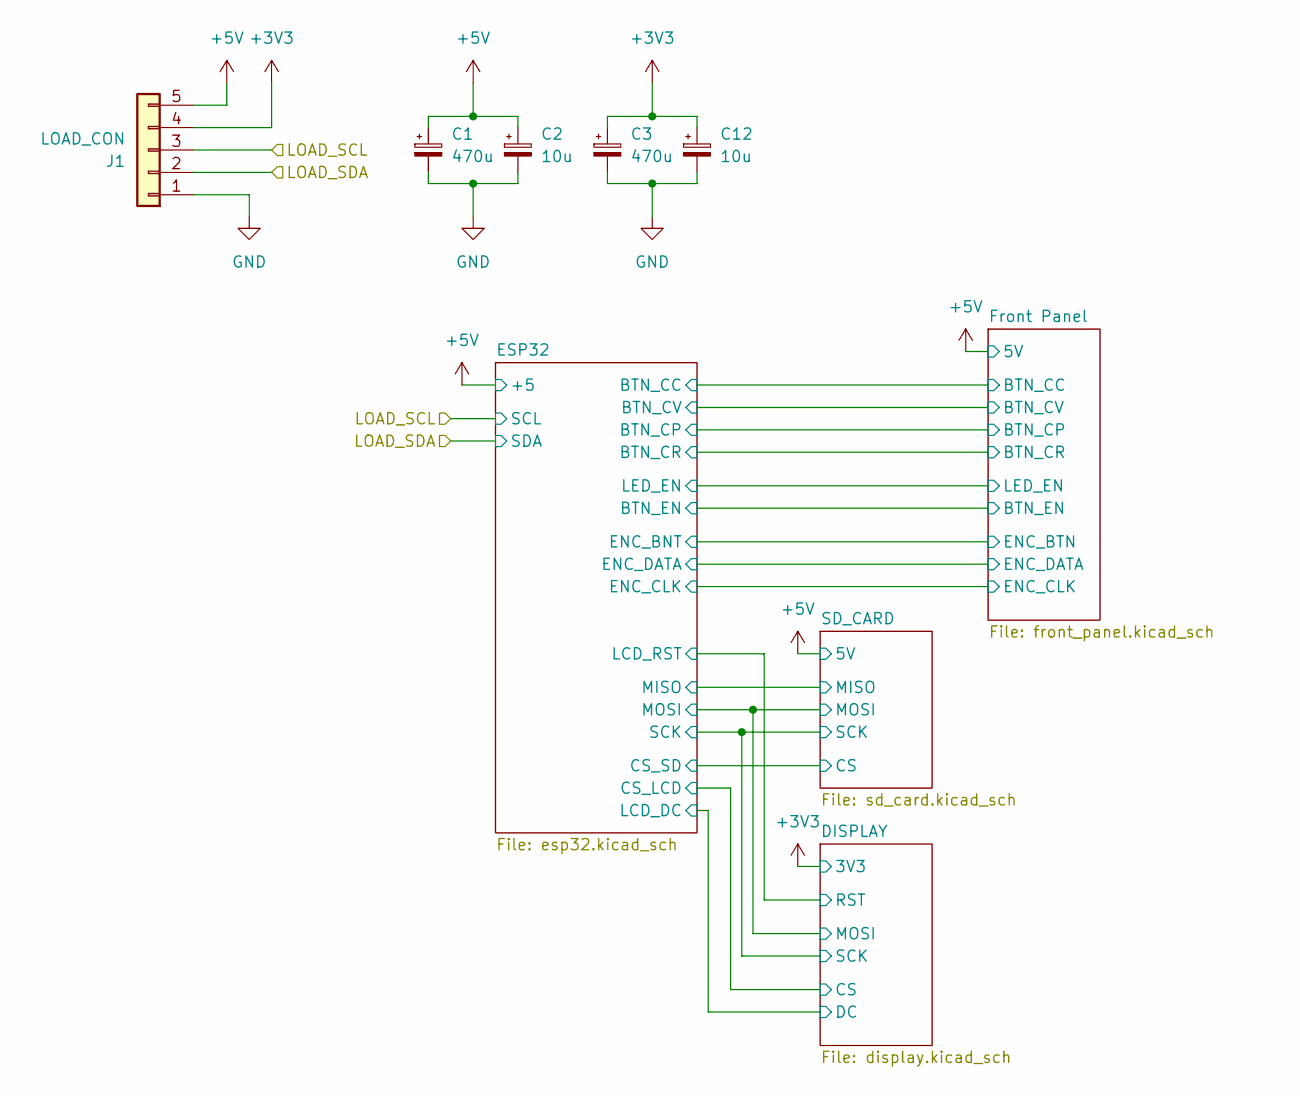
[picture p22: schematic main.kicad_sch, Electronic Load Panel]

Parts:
C1, C3: 470u; CP_Radial_D8.0mm_P5.00mm
C2, C12: 10u; CP_Radial_D5.0mm_P2.50mm
J1: LOAD_CON; PinSocket_1x05_P2.54mm_Vertical

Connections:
+3V3: C3.1, C12.1, J1.4; also elsewhere on the board
+5V: C1.1, C2.1, J1.5; also elsewhere on the board
/LOAD_SCL: J1.3; also elsewhere on the board
/LOAD_SDA: J1.2; also elsewhere on the board
GND: C1.2, C2.2, C3.2, C12.2, J1.1; also elsewhere on the board

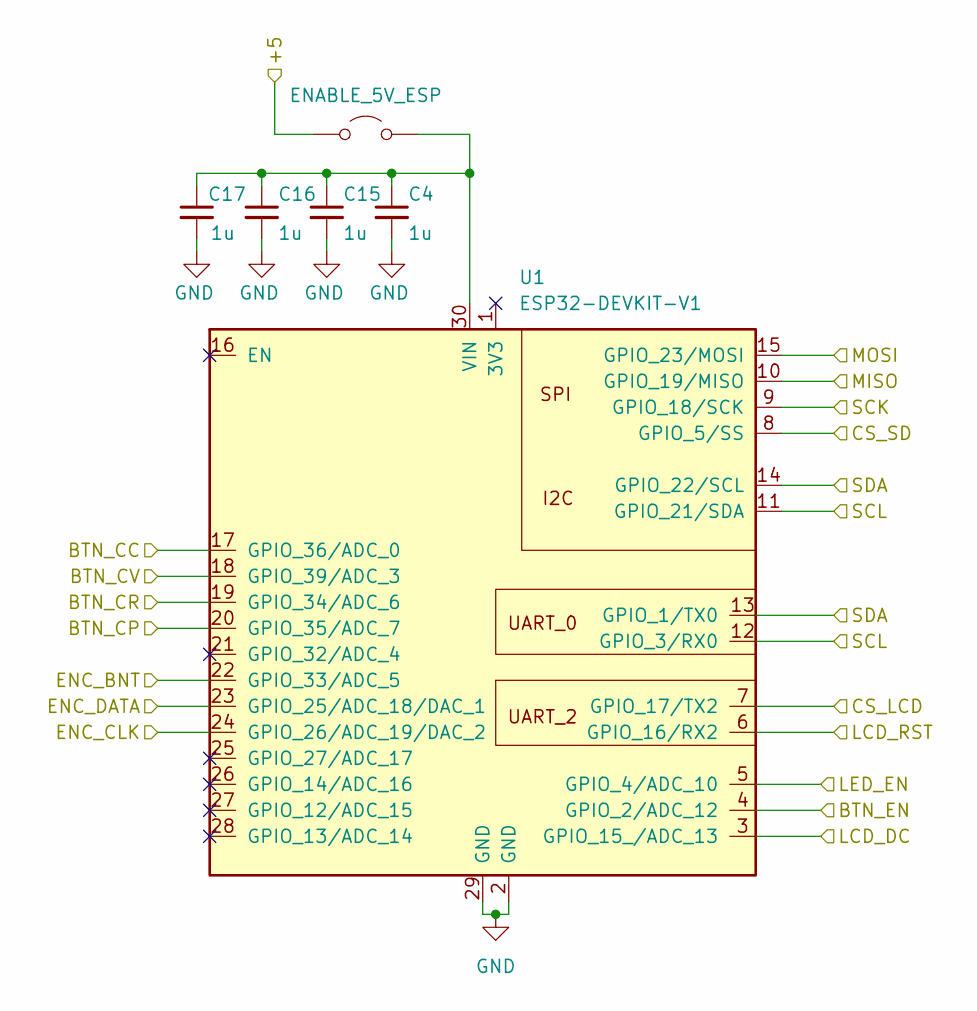
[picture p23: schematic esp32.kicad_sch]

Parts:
C4, C15, C16, C17: 1u; C_0805_2012Metric_Pad1.18x1.45mm_HandSolder
JP1: ENABLE_5V_ESP; SolderJumper-2_P1.3mm_Open_TrianglePad1.0x1.5mm
U1: ESP32-DEVKIT-V1; ESP32--DEVKIT-V1

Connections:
+5V: JP1.1 (A); also elsewhere on the board
/DISPLAY/CS: U1.7 (GPIO_17/TX2); also elsewhere on the board
/DISPLAY/DC: U1.3 (GPIO_15_/ADC_13); also elsewhere on the board
/DISPLAY/MOSI: U1.15 (GPIO_23/MOSI); also elsewhere on the board
/DISPLAY/RST: U1.6 (GPIO_16/RX2); also elsewhere on the board
/DISPLAY/SCK: U1.9 (GPIO_18/SCK); also elsewhere on the board
/ESP32/BTN_CC: U1.17 (GPIO_36/ADC_0); also elsewhere on the board
/ESP32/BTN_CP: U1.20 (GPIO_35/ADC_7); also elsewhere on the board
/ESP32/BTN_CR: U1.19 (GPIO_34/ADC_6); also elsewhere on the board
/ESP32/BTN_CV: U1.18 (GPIO_39/ADC_3); also elsewhere on the board
/ESP32/BTN_EN: U1.4 (GPIO_2/ADC_12); also elsewhere on the board
/ESP32/CS_SD: U1.8 (GPIO_5/SS); also elsewhere on the board
/ESP32/ENC_BNT: U1.22 (GPIO_33/ADC_5); also elsewhere on the board
/ESP32/ENC_CLK: U1.24 (GPIO_26/ADC_19/DAC_2); also elsewhere on the board
/ESP32/ENC_DATA: U1.23 (GPIO_25/ADC_18/DAC_1); also elsewhere on the board
/ESP32/LED_EN: U1.5 (GPIO_4/ADC_10); also elsewhere on the board
/ESP32/MISO: U1.10 (GPIO_19/MISO); also elsewhere on the board
/LOAD_SCL: U1.11 (GPIO_21/SDA), U1.12 (GPIO_3/RX0); also elsewhere on the board
/LOAD_SDA: U1.13 (GPIO_1/TX0), U1.14 (GPIO_22/SCL); also elsewhere on the board
GND: C4.2, C15.2, C16.2, C17.2, U1.2 (GND), U1.29 (GND); also elsewhere on the board
unnamed: C4.1, C15.1, C16.1, C17.1, JP1.2 (B), U1.30 (VIN)

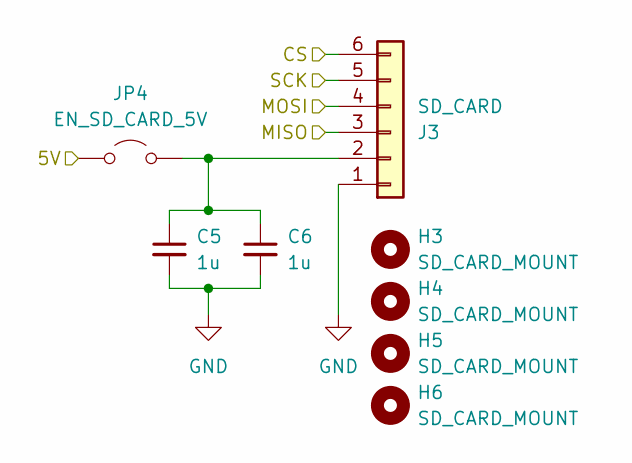
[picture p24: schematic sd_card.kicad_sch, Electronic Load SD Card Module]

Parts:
C5, C6: 1u; C_0805_2012Metric_Pad1.18x1.45mm_HandSolder
H3, H4, H5, H6: SD_CARD_MOUNT; MountingHole_2.2mm_M2
J3: SD_CARD; PinSocket_1x06_P2.54mm_Vertical
JP4: EN_SD_CARD_5V; SolderJumper-2_P1.3mm_Open_TrianglePad1.0x1.5mm

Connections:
+5V: JP4.1 (A); also elsewhere on the board
/DISPLAY/MOSI: J3.4; also elsewhere on the board
/DISPLAY/SCK: J3.5; also elsewhere on the board
/ESP32/CS_SD: J3.6; also elsewhere on the board
/ESP32/MISO: J3.3; also elsewhere on the board
GND: C5.2, C6.2, J3.1; also elsewhere on the board
unnamed: C5.1, C6.1, J3.2, JP4.2 (B)

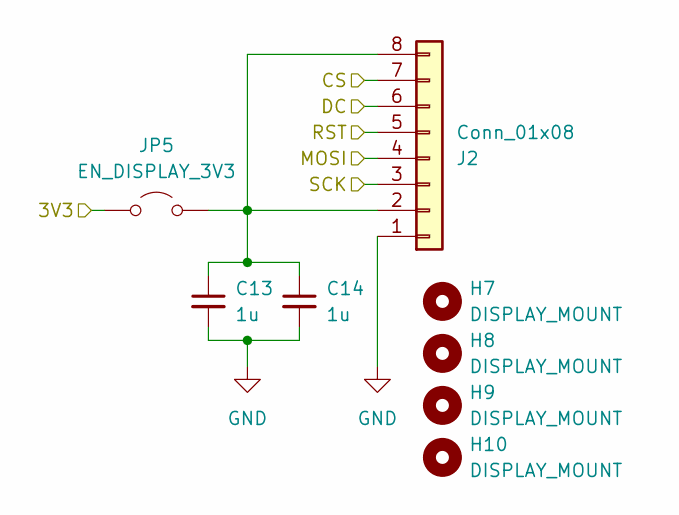
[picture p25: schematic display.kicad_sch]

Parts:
C13, C14: 1u; C_0805_2012Metric_Pad1.18x1.45mm_HandSolder
H7, H8, H9, H10: DISPLAY_MOUNT; MountingHole_2.2mm_M2
J2: Conn_01x08; PinSocket_1x08_P2.54mm_Vertical
JP5: EN_DISPLAY_3V3; SolderJumper-2_P1.3mm_Open_TrianglePad1.0x1.5mm

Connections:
+3V3: JP5.1 (A); also elsewhere on the board
/DISPLAY/CS: J2.7; also elsewhere on the board
/DISPLAY/DC: J2.6; also elsewhere on the board
/DISPLAY/MOSI: J2.4; also elsewhere on the board
/DISPLAY/RST: J2.5; also elsewhere on the board
/DISPLAY/SCK: J2.3; also elsewhere on the board
GND: C13.2, C14.2, J2.1; also elsewhere on the board
unnamed: C13.1, C14.1, J2.2, J2.8, JP5.2 (B)

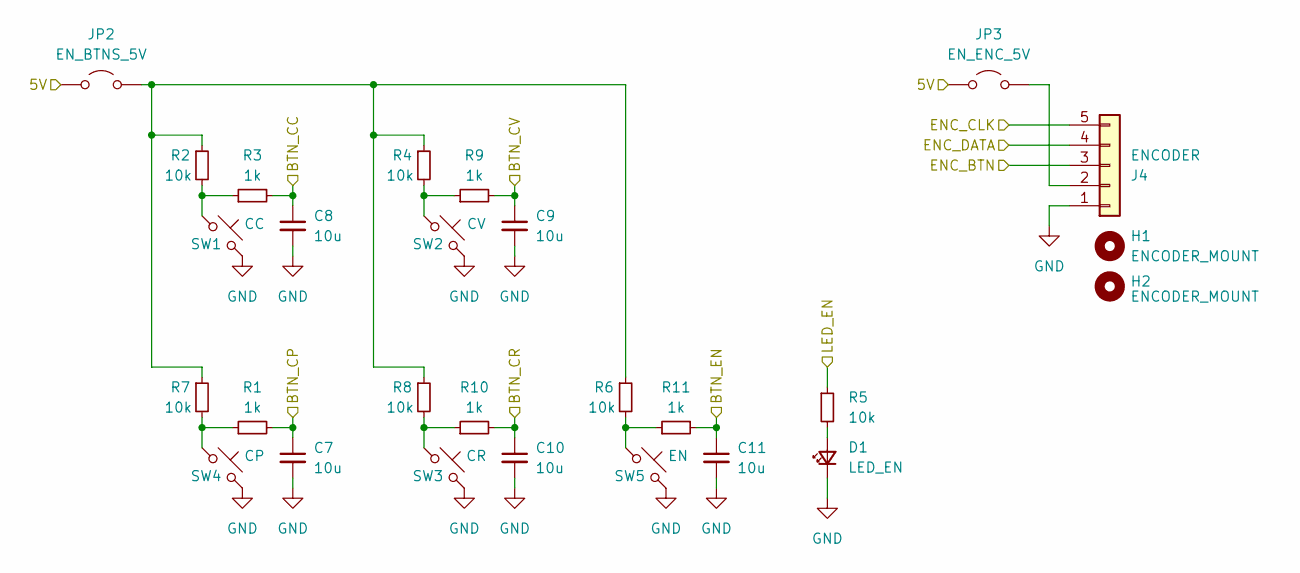
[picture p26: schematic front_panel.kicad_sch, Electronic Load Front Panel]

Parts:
C7, C8, C9, C10, C11: 10u; C_0805_2012Metric_Pad1.18x1.45mm_HandSolder
D1: LED_EN; LED_D3.0mm
H1, H2: ENCODER_MOUNT; MountingHole_3mm
J4: ENCODER; PinSocket_1x05_P2.54mm_Vertical
JP2: EN_BTNS_5V; SolderJumper-2_P1.3mm_Open_TrianglePad1.0x1.5mm
JP3: EN_ENC_5V; SolderJumper-2_P1.3mm_Open_TrianglePad1.0x1.5mm
R1, R3, R9, R10, R11: 1k; R_0805_2012Metric_Pad1.20x1.40mm_HandSolder
R2, R4, R5, R6, R7, R8: 10k; R_0805_2012Metric_Pad1.20x1.40mm_HandSolder
SW1: CC; SW_PUSH-12mm_Wuerth-430476085716
SW2: CV; SW_PUSH-12mm_Wuerth-430476085716
SW3: CR; SW_PUSH-12mm_Wuerth-430476085716
SW4: CP; SW_PUSH-12mm_Wuerth-430476085716
SW5: EN; SW_PUSH-12mm_Wuerth-430476085716

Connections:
+5V: JP2.1 (A), JP3.1 (A); also elsewhere on the board
/ESP32/BTN_CC: C8.1, R3.2; also elsewhere on the board
/ESP32/BTN_CP: C7.1, R1.2; also elsewhere on the board
/ESP32/BTN_CR: C10.1, R10.2; also elsewhere on the board
/ESP32/BTN_CV: C9.1, R9.2; also elsewhere on the board
/ESP32/BTN_EN: C11.1, R11.2; also elsewhere on the board
/ESP32/ENC_BNT: J4.3; also elsewhere on the board
/ESP32/ENC_CLK: J4.5; also elsewhere on the board
/ESP32/ENC_DATA: J4.4; also elsewhere on the board
/ESP32/LED_EN: R5.1; also elsewhere on the board
GND: C7.2, C8.2, C9.2, C10.2, C11.2, D1.1 (K), J4.1, SW1.2, SW2.2, SW3.2, SW4.2, SW5.2; also elsewhere on the board
unnamed: D1.2 (A), R5.2
unnamed: J4.2, JP3.2 (B)
unnamed: JP2.2 (B), R2.1, R4.1, R6.1, R7.1, R8.1
unnamed: R1.1, R7.2, SW4.1
unnamed: R2.2, R3.1, SW1.1
unnamed: R4.2, R9.1, SW2.1
unnamed: R8.2, R10.1, SW3.1
unnamed: R6.2, R11.1, SW5.1

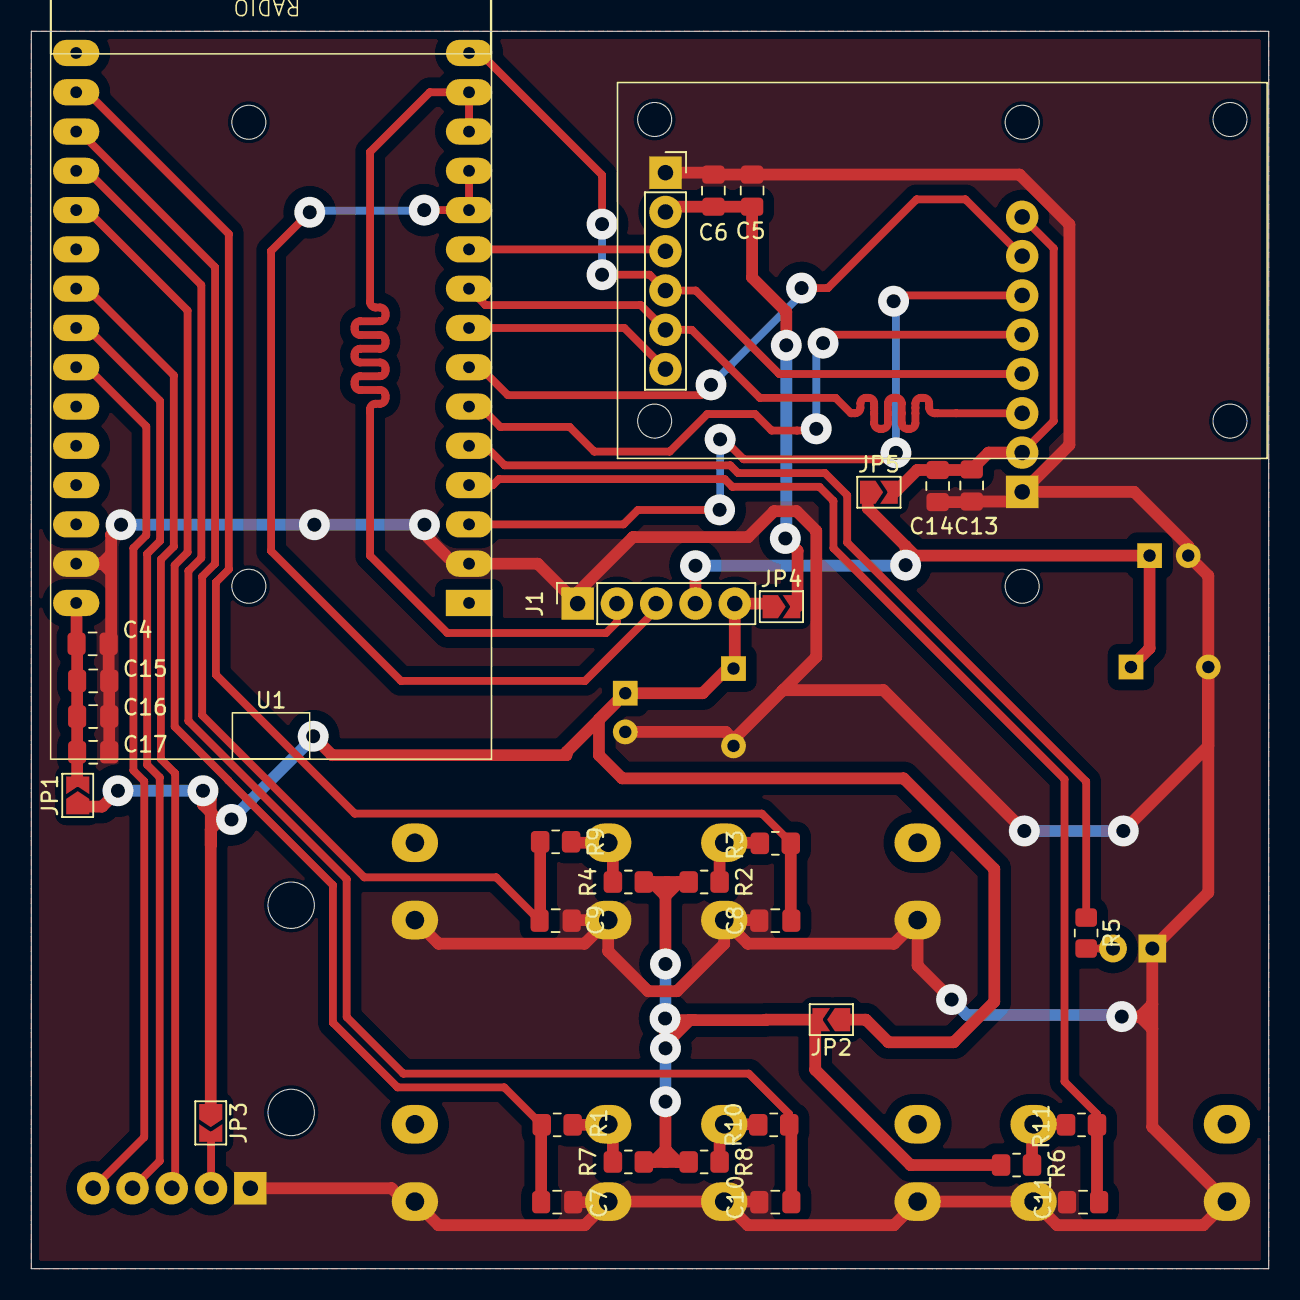
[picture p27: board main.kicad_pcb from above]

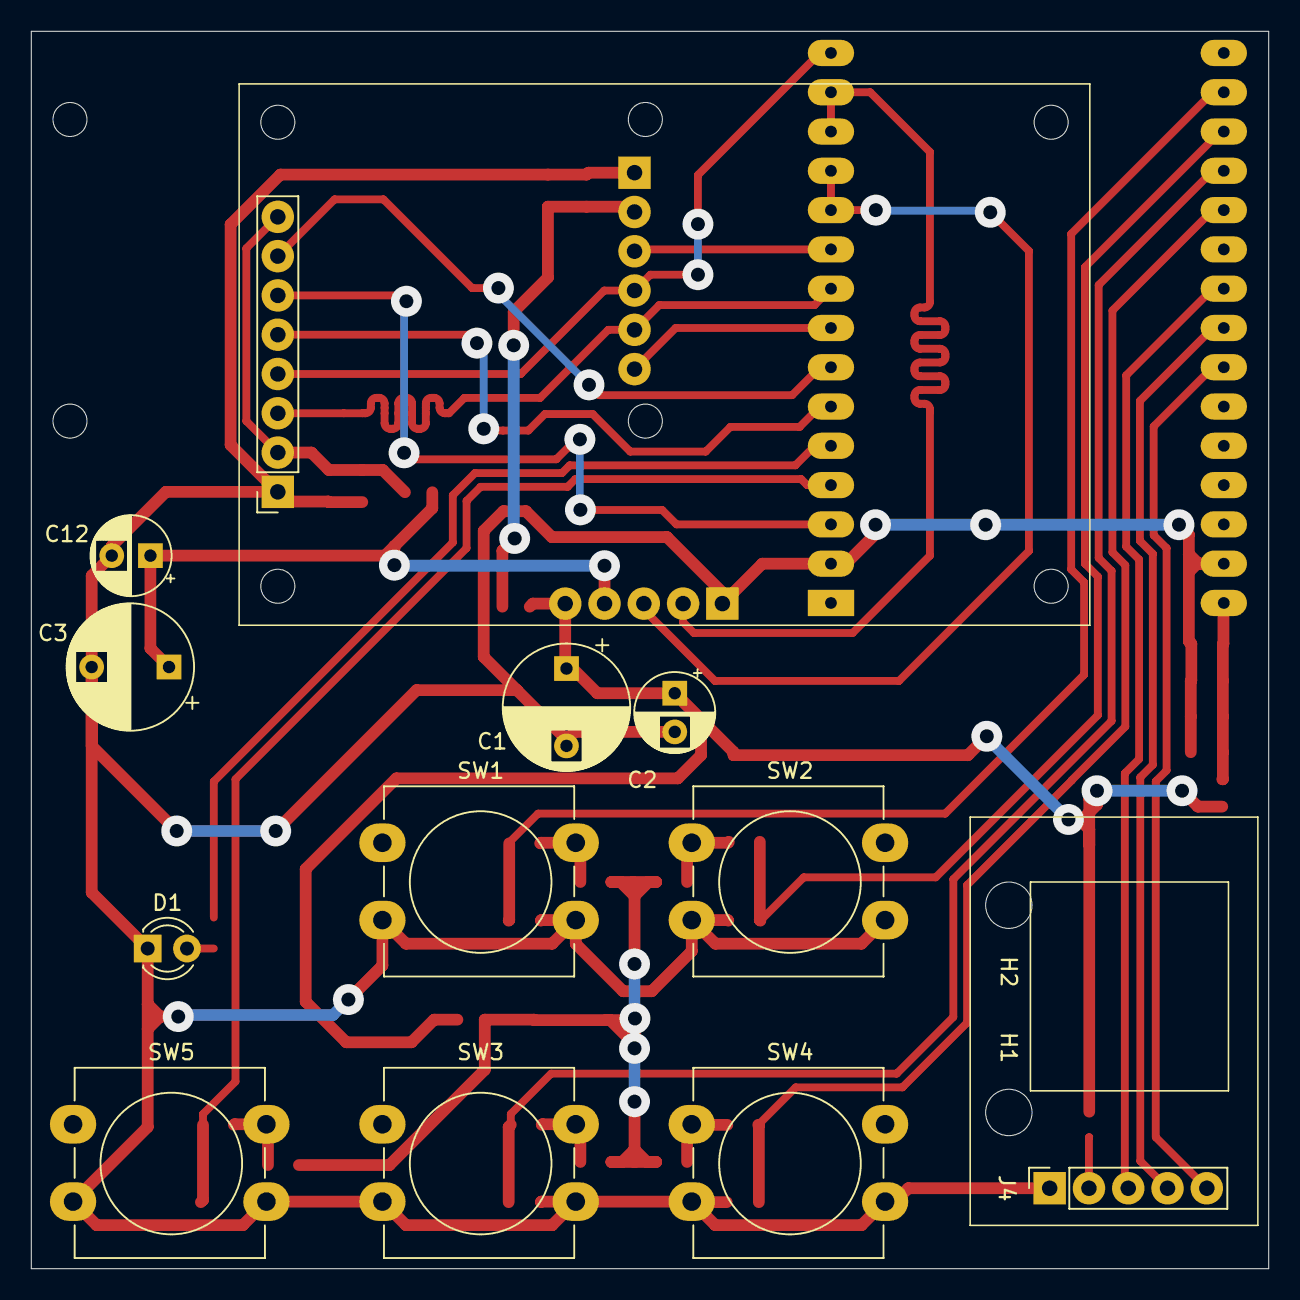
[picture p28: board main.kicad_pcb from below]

Board: 2 copper layers, 80.0 x 80.0 mm, 54 parts (18 on the bottom side), 32 nets.

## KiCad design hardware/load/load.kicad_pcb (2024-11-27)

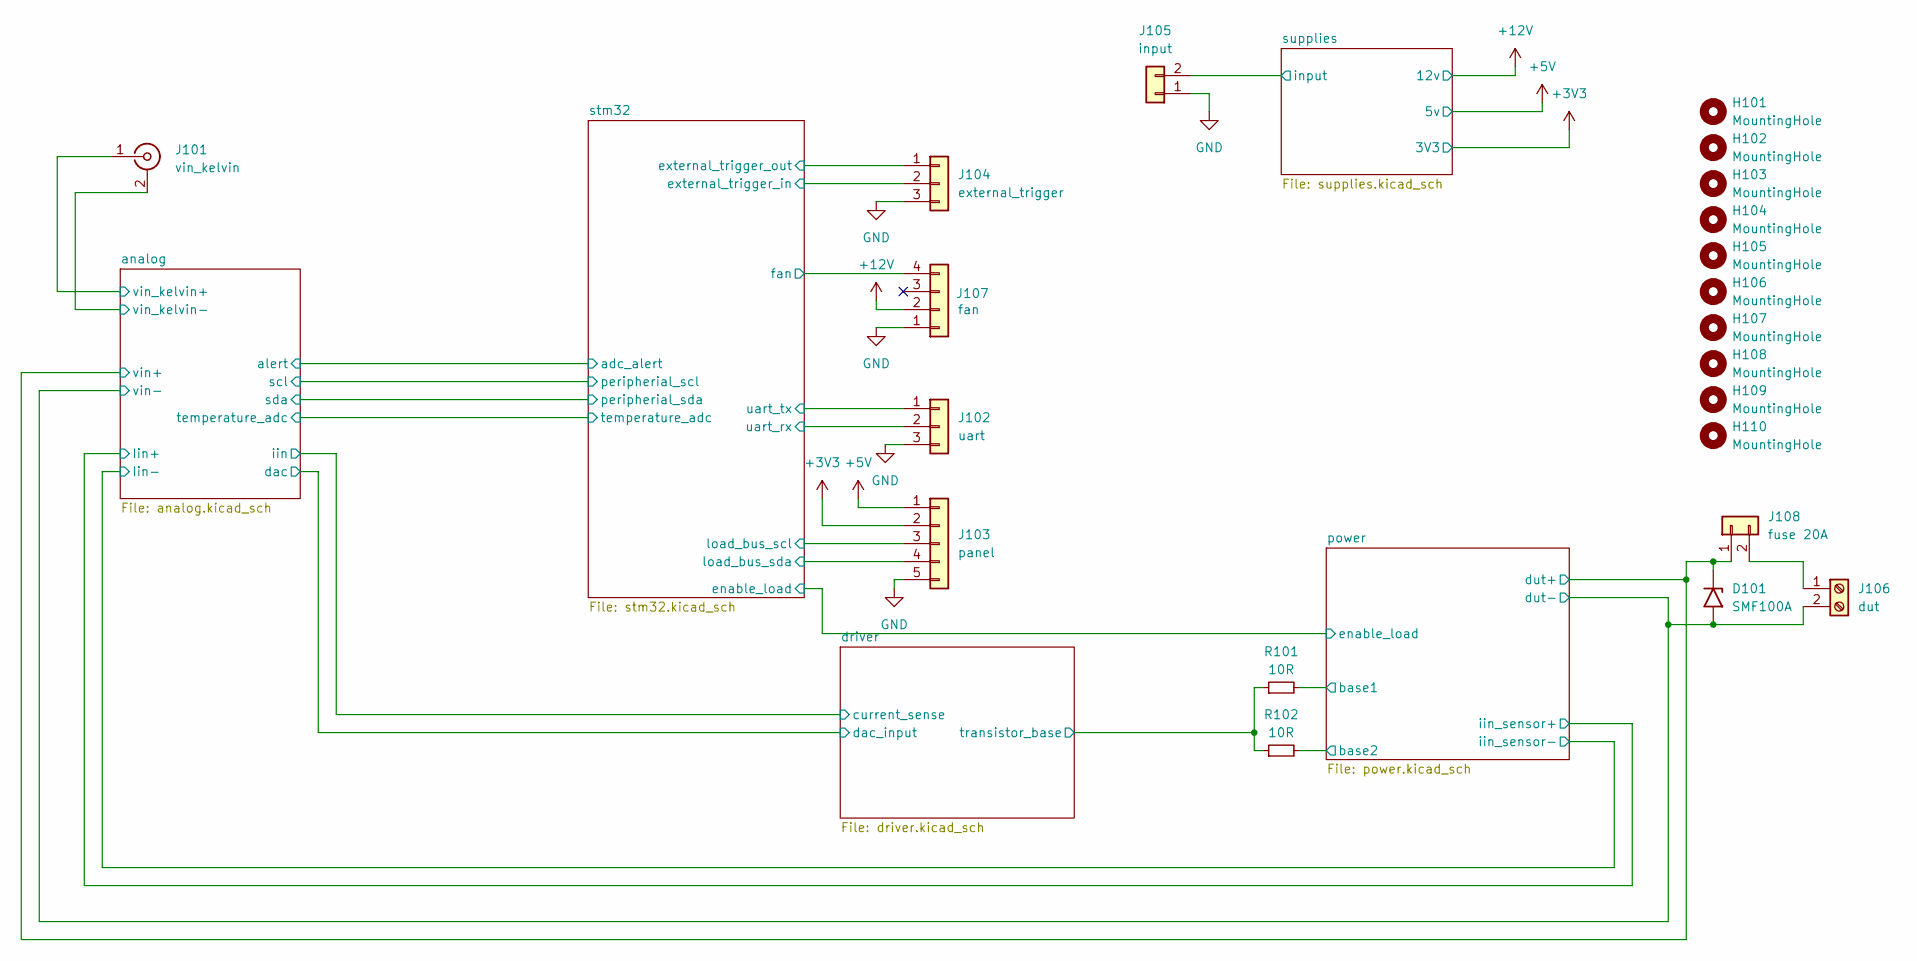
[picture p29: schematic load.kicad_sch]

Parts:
D101: SMF100A; D_SMF
H101, H102, H103, H104, H105, H106, H107, H108, H109, H110: MountingHole; MountingHole_3.2mm_M3
J101: vin_kelvin; RCA
J102: uart; PinHeader_1x03_P2.54mm_Vertical
J103: panel; PinHeader_1x05_P2.54mm_Vertical
J104: external_trigger; TerminalBlock_bornier-3_P5.08mm
J105: input; TerminalBlock_bornier-2_P5.08mm
J106: dut; Banana_PCB_2Pin
J107: fan; FanPinHeader_1x04_P2.54mm_Vertical
J108: fuse 20A; TerminalBlock_bornier-2_P5.08mm
R101, R102: 10R; R_0805_2012Metric_Pad1.20x1.40mm_HandSolder

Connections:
+3V3: J103.2; also elsewhere on the board
+5V: J103.1; also elsewhere on the board
+12V: J107.2; also elsewhere on the board
/analog/vin+: D101.1 (A1), J108.1; also elsewhere on the board
/analog/vin_kelvin+: J101.1 (In); also elsewhere on the board
/analog/vin_kelvin-: J101.2 (Ext); also elsewhere on the board
/driver/transistor_base: R101.1, R102.1; also elsewhere on the board
/power/base1: R101.2; also elsewhere on the board
/power/base2: R102.2; also elsewhere on the board
/stm32/external_trigger_in: J104.2; also elsewhere on the board
/stm32/external_trigger_out: J104.1; also elsewhere on the board
/stm32/fan: J107.4; also elsewhere on the board
/stm32/load_bus_scl: J103.3; also elsewhere on the board
/stm32/load_bus_sda: J103.4; also elsewhere on the board
/stm32/uart_rx: J102.2; also elsewhere on the board
/stm32/uart_tx: J102.1; also elsewhere on the board
/supplies/input: J105.2; also elsewhere on the board
GND: J102.3, J103.5, J104.3, J105.1, J107.1; also elsewhere on the board
GNDPWR: D101.2 (A2), J106.2; also elsewhere on the board
unnamed: J106.1, J108.2

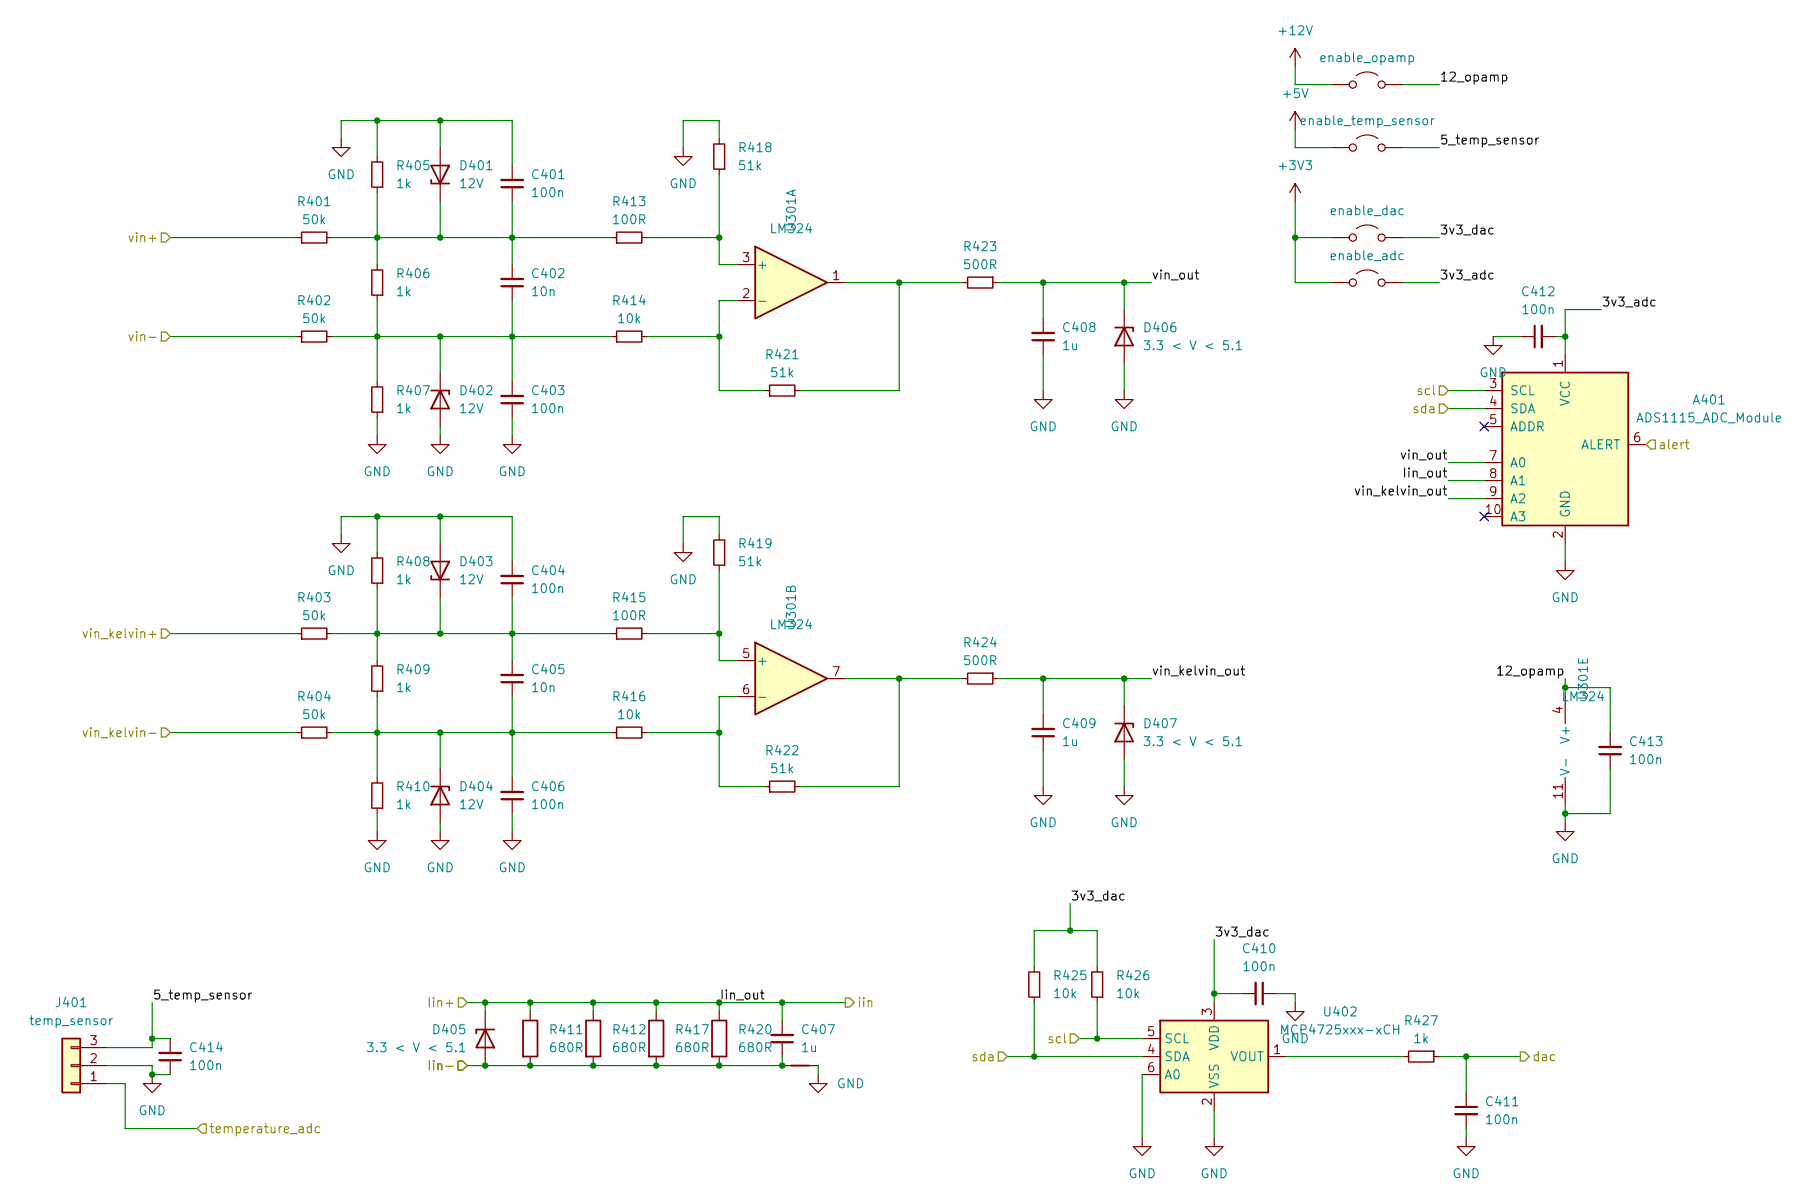
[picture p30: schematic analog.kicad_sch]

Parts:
A401: ADS1115_ADC_Module; ADC1115_ADC_Module
C401, C403, C404, C406, C410, C411, C412, C413, C414: 100n; C_0805_2012Metric_Pad1.18x1.45mm_HandSolder
C402, C405: 10n; C_0805_2012Metric_Pad1.18x1.45mm_HandSolder
C407, C408, C409: 1u; C_0805_2012Metric_Pad1.18x1.45mm_HandSolder
D401, D402, D403, D404: 12V; D_MiniMELF
D405, D406, D407: 3.3 < V < 5.1; D_MiniMELF
J401: temp_sensor; PinHeader_1x03_P2.54mm_Vertical
JP401: enable_dac; SolderJumper-2_P1.3mm_Open_TrianglePad1.0x1.5mm
JP402: enable_adc; SolderJumper-2_P1.3mm_Open_TrianglePad1.0x1.5mm
JP403: enable_opamp; SolderJumper-2_P1.3mm_Open_TrianglePad1.0x1.5mm
JP404: enable_temp_sensor; SolderJumper-2_P1.3mm_Open_TrianglePad1.0x1.5mm
NT401: NetTie_2; NetTie-2_SMD_Pad0.5mm
R401, R402, R403, R404: 50k; R_0805_2012Metric_Pad1.20x1.40mm_HandSolder
R405, R406, R407, R408, R409, R410, R427: 1k; R_0805_2012Metric_Pad1.20x1.40mm_HandSolder
R411, R412, R417, R420: 680R; R_0805_2012Metric_Pad1.20x1.40mm_HandSolder
R413, R415: 100R; R_0805_2012Metric_Pad1.20x1.40mm_HandSolder
R414, R416, R425, R426: 10k; R_0805_2012Metric_Pad1.20x1.40mm_HandSolder
R418, R419, R421, R422: 51k; R_0805_2012Metric_Pad1.20x1.40mm_HandSolder
R423, R424: 500R; R_0805_2012Metric_Pad1.20x1.40mm_HandSolder
U301: LM324; SOIC-14_3.9x8.7mm_P1.27mm
U402: MCP4725xxx-xCH; SOT-23-6

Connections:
+3V3: JP401.1 (A), JP402.2 (B); also elsewhere on the board
+5V: JP404.2 (B); also elsewhere on the board
+12V: JP403.2 (B); also elsewhere on the board
/analog/3v3_adc: A401.1 (VCC), C412.2, JP402.1 (A)
/analog/3v3_dac: C410.2, JP401.2 (B), R425.2, R426.2, U402.3 (VDD)
/analog/5_temp_sensor: C414.2, J401.3, JP404.1 (A)
/analog/12_opamp: C413.2, JP403.1 (A), U301.4 (V+)
/analog/Iin-: C407.1, D405.2 (A), NT401.2, R411.2, R412.2, R417.2, R420.2; also elsewhere on the board
/analog/Iin_out: A401.8 (A1), C407.2, D405.1 (K), R411.1, R412.1, R417.1, R420.1; also elsewhere on the board
/analog/alert: A401.6 (ALERT); also elsewhere on the board
/analog/dac: C411.1, R427.1; also elsewhere on the board
/analog/scl: A401.3 (SCL), R426.1, U402.5 (SCL); also elsewhere on the board
/analog/sda: A401.4 (SDA), R425.1, U402.4 (SDA); also elsewhere on the board
/analog/temperature_adc: J401.1; also elsewhere on the board
/analog/vin+: R401.1; also elsewhere on the board
/analog/vin_kelvin+: R403.1; also elsewhere on the board
/analog/vin_kelvin-: R404.1; also elsewhere on the board
/analog/vin_kelvin_out: A401.9 (A2), C409.2, D407.1 (K), R424.1
/analog/vin_out: A401.7 (A0), C408.2, D406.1 (K), R423.1
GND: A401.2 (GND), C401.2, C403.1, C404.2, C406.1, C408.1, C409.1, C410.1, C411.2, C412.1, C413.1, C414.1, D401.2 (A), D402.2 (A), D403.2 (A), D404.2 (A), D406.2 (A), D407.2 (A), J401.2, NT401.1, R405.2, R407.1, R408.2, R410.1, R418.2, R419.2, U301.11 (V-), U402.2 (VSS), U402.6 (A0); also elsewhere on the board
GNDPWR: R402.1; also elsewhere on the board
unnamed: C401.1, C402.2, D401.1 (K), R401.2, R405.1, R406.2, R413.1
unnamed: C402.1, C403.2, D402.1 (K), R402.2, R406.1, R407.2, R414.1
unnamed: C404.1, C405.2, D403.1 (K), R403.2, R408.1, R409.2, R415.1
unnamed: C405.1, C406.2, D404.1 (K), R404.2, R409.1, R410.2, R416.1
unnamed: R421.2, R423.2, U301.1
unnamed: R422.2, R424.2, U301.7
unnamed: R413.2, R418.1, U301.3 (+)
unnamed: R414.2, R421.1, U301.2 (-)
unnamed: R415.2, R419.1, U301.5 (+)
unnamed: R416.2, R422.1, U301.6 (-)
unnamed: R427.2, U402.1 (VOUT)

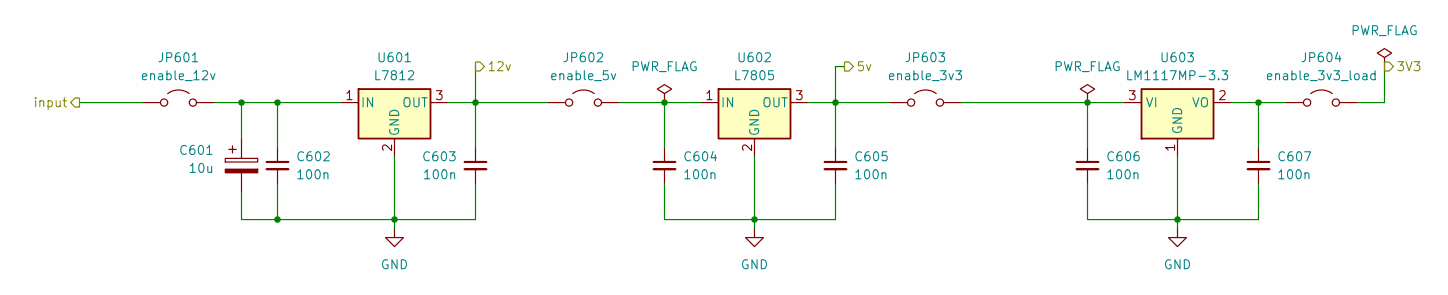
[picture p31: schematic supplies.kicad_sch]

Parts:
C601: 10u; CP_Radial_D8.0mm_P3.50mm
C602, C603, C604, C605, C606, C607: 100n; C_0805_2012Metric_Pad1.18x1.45mm_HandSolder
JP601: enable_12v; SolderJumper-2_P1.3mm_Open_TrianglePad1.0x1.5mm
JP602: enable_5v; SolderJumper-2_P1.3mm_Open_TrianglePad1.0x1.5mm
JP603: enable_3v3; SolderJumper-2_P1.3mm_Open_TrianglePad1.0x1.5mm
JP604: enable_3v3_load; SolderJumper-2_P1.3mm_Open_TrianglePad1.0x1.5mm
U601: L7812; TO-220-3_Vertical
U602: L7805; TO-220-3_Vertical
U603: LM1117MP-3.3; SOT-223-3_TabPin2

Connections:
+3V3: JP604.2 (B); also elsewhere on the board
+5V: C605.1, JP603.1 (A), U602.3 (OUT); also elsewhere on the board
+12V: C603.1, JP602.1 (A), U601.3 (OUT); also elsewhere on the board
/supplies/input: JP601.1 (A); also elsewhere on the board
GND: C601.2, C602.2, C603.2, C604.2, C605.2, C606.2, C607.2, U601.2 (GND), U602.2 (GND), U603.1 (GND); also elsewhere on the board
unnamed: C601.1, C602.1, JP601.2 (B), U601.1 (IN)
unnamed: C604.1, JP602.2 (B), U602.1 (IN)
unnamed: C606.1, JP603.2 (B), U603.3 (VI)
unnamed: C607.1, JP604.1 (A), U603.2 (VO)

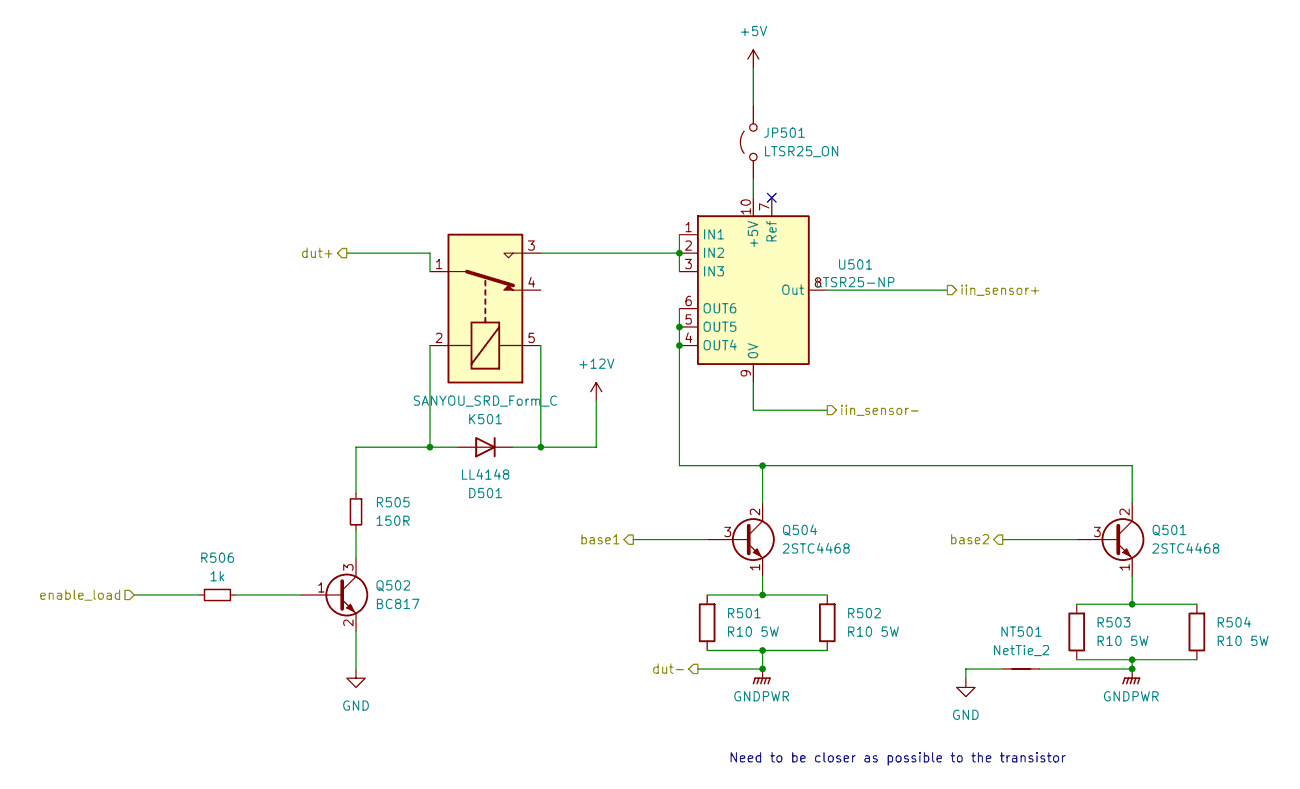
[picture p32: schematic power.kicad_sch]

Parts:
D501: LL4148; D_MiniMELF
JP501: LTSR25_ON; SolderJumper-2_P1.3mm_Open_TrianglePad1.0x1.5mm
K501: SANYOU_SRD_Form_C; Relay_SPDT_SANYOU_SRD_Series_Form_C
NT501: NetTie_2; NetTie-2_SMD_Pad0.5mm
Q501, Q504: 2STC4468; TerminalBlock_bornier-3_P5.08mm
Q502: BC817; SOT-23
R501, R502, R503, R504: R10 5W; R_Box_L14.0mm_W5.0mm_P9.00mm
R505: 150R; R_0805_2012Metric_Pad1.20x1.40mm_HandSolder
R506: 1k; R_0805_2012Metric_Pad1.20x1.40mm_HandSolder
U501: LTSR25-NP; LEM_LTSR-NP

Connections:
+5V: JP501.2 (B); also elsewhere on the board
+12V: D501.1 (K), K501.5; also elsewhere on the board
/analog/Iin-: U501.9 (0V); also elsewhere on the board
/analog/Iin_out: U501.8 (Out); also elsewhere on the board
/analog/vin+: K501.1; also elsewhere on the board
/power/base1: Q504.3 (B); also elsewhere on the board
/power/base2: Q501.3 (B); also elsewhere on the board
/power/enable_load: R506.1
GND: NT501.2, Q502.2 (E); also elsewhere on the board
GNDPWR: NT501.1, R501.1, R502.1, R503.1, R504.1; also elsewhere on the board
unnamed: D501.2 (A), K501.2, R505.1
unnamed: JP501.1 (A), U501.10 (+5V)
unnamed: Q501.2 (C), Q504.2 (C), U501.4 (OUT4), U501.5 (OUT5), U501.6 (OUT6)
unnamed: Q501.1 (E), R503.2, R504.2
unnamed: Q502.1 (B), R506.2
unnamed: Q502.3 (C), R505.2
unnamed: Q504.1 (E), R501.2, R502.2
unnamed: K501.3, U501.1 (IN1), U501.2 (IN2), U501.3 (IN3)

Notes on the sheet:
Need to be closer as possible to the transistor

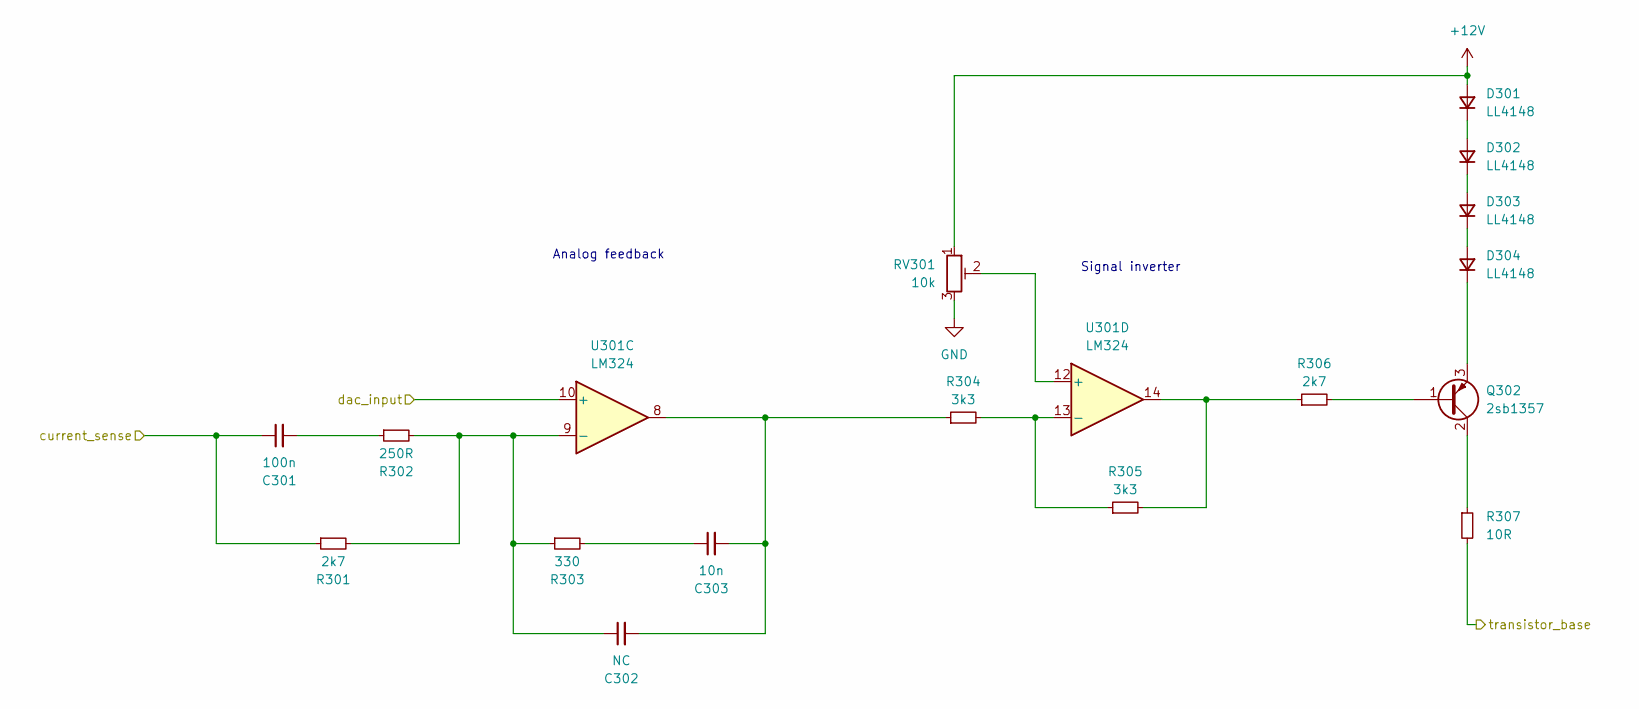
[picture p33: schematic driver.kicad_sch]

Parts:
C301: 100n; C_0805_2012Metric_Pad1.18x1.45mm_HandSolder
C302: NC; C_0805_2012Metric_Pad1.18x1.45mm_HandSolder
C303: 10n; C_0805_2012Metric_Pad1.18x1.45mm_HandSolder
D301, D302, D303, D304: LL4148; D_MiniMELF
Q302: 2sb1357; TO-126-3_Vertical
R301, R306: 2k7; R_0805_2012Metric_Pad1.20x1.40mm_HandSolder
R302: 250R; R_0805_2012Metric_Pad1.20x1.40mm_HandSolder
R303: 330; R_0805_2012Metric_Pad1.20x1.40mm_HandSolder
R304, R305: 3k3; R_0805_2012Metric_Pad1.20x1.40mm_HandSolder
R307: 10R; R_0805_2012Metric_Pad1.20x1.40mm_HandSolder
RV301: 10k; Potentiometer_Bourns_3386W_Horizontal
U301: LM324; SOIC-14_3.9x8.7mm_P1.27mm

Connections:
+12V: D301.2 (A), RV301.1; also elsewhere on the board
/analog/Iin_out: C301.1, R301.1; also elsewhere on the board
/analog/dac: U301.10 (+); also elsewhere on the board
/driver/transistor_base: R307.2; also elsewhere on the board
GND: RV301.3; also elsewhere on the board
unnamed: C301.2, R302.1
unnamed: C302.2, C303.2, R304.1, U301.8
unnamed: C303.1, R303.2
unnamed: D301.1 (K), D302.2 (A)
unnamed: D302.1 (K), D303.2 (A)
unnamed: D303.1 (K), D304.2 (A)
unnamed: D304.1 (K), Q302.3 (E)
unnamed: Q302.1 (B), R306.2
unnamed: Q302.2 (C), R307.1
unnamed: R305.2, R306.1, U301.14
unnamed: C302.1, R301.2, R302.2, R303.1, U301.9 (-)
unnamed: RV301.2, U301.12 (+)
unnamed: R304.2, R305.1, U301.13 (-)

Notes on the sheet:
Signal inverter
Analog feedback

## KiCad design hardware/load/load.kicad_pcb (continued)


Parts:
C201, C202: 100n; C_0805_2012Metric_Pad1.18x1.45mm_HandSolder
D201: led_red; LED_0805_2012Metric_Pad1.15x1.40mm_HandSolder
D202: led_green; LED_0805_2012Metric_Pad1.15x1.40mm_HandSolder
D203, D204: 3.3 < V < 5.1; D_MiniMELF
JP201: enable_5v_stm; SolderJumper-2_P1.3mm_Open_TrianglePad1.0x1.5mm
JP202: enable_3v3_stm; SolderJumper-2_P1.3mm_Open_TrianglePad1.0x1.5mm
R201, R202: 1k; R_0805_2012Metric_Pad1.20x1.40mm_HandSolder
R203, R204: 2.2k; R_0805_2012Metric_Pad1.20x1.40mm_HandSolder
U201: BluePill

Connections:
+3V3: JP202.1 (A); also elsewhere on the board
+5V: JP201.1 (A); also elsewhere on the board
/analog/alert: U201.34 (PB1); also elsewhere on the board
/analog/scl: U201.35 (PB10); also elsewhere on the board
/analog/sda: U201.36 (PB11); also elsewhere on the board
/analog/temperature_adc: U201.25 (PA0); also elsewhere on the board
/stm32/enable_3v3_stm: C202.1, JP202.2 (B), U201.20 (3V3), U201.38 (3V3)
/stm32/enable_5v_stm: C201.2, JP201.2 (B), U201.18 (5V)
/stm32/external_trigger_in: R203.1; also elsewhere on the board
/stm32/external_trigger_out: R204.1; also elsewhere on the board
/stm32/fan: U201.5 (PA8); also elsewhere on the board
/stm32/load_bus_scl: U201.14 (PB6); also elsewhere on the board
/stm32/load_bus_sda: U201.15 (PB7); also elsewhere on the board
/stm32/uart_rx: U201.7 (PA10); also elsewhere on the board
/stm32/uart_tx: U201.6 (PA9); also elsewhere on the board
GND: C201.1, C202.2, D201.1 (K), D202.1 (K), D203.2 (A), D204.2 (A), U201.19 (GND), U201.39 (GND), U201.40 (GND); also elsewhere on the board
unnamed: D201.2 (A), R201.2
unnamed: D202.2 (A), R202.2
unnamed: D203.1 (K), R204.2, U201.22 (PC13)
unnamed: D204.1 (K), R203.2, U201.23 (PC14)
unnamed: R201.1, U201.32 (PA7)
unnamed: R202.1, U201.33 (PB0)



Board: 2 copper layers, 107.5 x 120.0 mm, 135 parts (102 on the bottom side), 77 nets.

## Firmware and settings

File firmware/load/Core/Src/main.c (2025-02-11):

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
/* Includes ------------------------------------------------------------------*/
#include "main.h"

/* USER CODE BEGIN Includes */
#include <stdio.h>
#include <mcp4725.h>
#include <ads111x.h>
#include <adc.h>
#include <uart.h>
#include <fan.h>
#include <control.h>
#include <utils.h>
/* USER CODE END Includes */

ADC_HandleTypeDef hadc1;
DMA_HandleTypeDef hdma_adc1;

I2C_HandleTypeDef hi2c2;

RTC_HandleTypeDef hrtc;

TIM_HandleTypeDef htim1;
TIM_HandleTypeDef htim3;

UART_HandleTypeDef huart1;
DMA_HandleTypeDef hdma_usart1_rx;
DMA_HandleTypeDef hdma_usart1_tx;

/* USER CODE BEGIN PV */
extern float dac_voltage;
extern uint8_t enable;

int _write(int fd __attribute__((unused)), char *ptr, int len)
{
  HAL_UART_Transmit(&huart1, (uint8_t *)ptr, len, HAL_MAX_DELAY);
  return len;
}

/* USER CODE END PV */

void SystemClock_Config(void);
static void MX_GPIO_Init(void);
static void MX_DMA_Init(void);
static void MX_ADC1_Init(void);
static void MX_I2C2_Init(void);
static void MX_RTC_Init(void);
static void MX_TIM1_Init(void);
static void MX_USART1_UART_Init(void);
static void MX_TIM3_Init(void);
/* USER CODE BEGIN PFP */
uint8_t data[6] = {0};
extern uint32_t trigger_test;
/* USER CODE END PFP */

/* USER CODE BEGIN 0 */
void error_handler(void)
{
  while (1)
  {
    HAL_GPIO_TogglePin(LED_RED_GPIO_Port, LED_RED_Pin);
    HAL_Delay(100);
  }
}

volatile uint32_t adc_ready = 0;
void HAL_GPIO_EXTI_Callback(uint16_t GPIO_Pin)
{
  if (GPIO_Pin == ADC_ALERT_Pin)
  {
    adc_ready = 1;
  }
}

/* USER CODE END 0 */

/**
  * @brief  The application entry point.
  * @retval int
  */
int main(void)
{

  /* MCU Configuration--------------------------------------------------------*/

  /* Reset of all peripherals, Initializes the Flash interface and the Systick. */
  HAL_Init();

  /* Configure the system clock */
  SystemClock_Config();

  /* Initialize all configured peripherals */
  MX_GPIO_Init();
  MX_DMA_Init();
  MX_ADC1_Init();
  MX_I2C2_Init();
  MX_RTC_Init();
  MX_TIM1_Init();
  MX_USART1_UART_Init();
  MX_TIM3_Init();
  /* USER CODE BEGIN 2 */
  // MCP4725 device descriptor
  mcp4725_t dac;
  control_t control;

  // Initialize MCP4725 device
  if (mcp4725_init(&dac, &hi2c2, MCP4725_I2C_ADDR) != HAL_OK)
  {
    error_handler();
  }

  adc_init(&hi2c2, &hadc1);
  uart_init(&huart1);
  fan_init(&htim1);
  control_init(&control, &dac);

  HAL_TIM_Base_Start_IT(&htim3);

  HAL_GPIO_WritePin(ENABLE_LOAD_GPIO_Port, ENABLE_LOAD_Pin, GPIO_PIN_RESET);
  /* USER CODE END 2 */

  /* Infinite loop */
  /* USER CODE BEGIN WHILE */
  while (1)
  {

    /* Measure adc */
    if (adc_ready)
    {
      if (adc_measure() != HAL_OK)
      {
        LOG_ERROR("Error reading ADC\n");
      }

      adc_ready = 0;
    }

    if (adc_all_channels_measured())
    {
      adc_calculate_average();
      control_set_from_server(&control, &(h_load_state.control));
      control_update(&control);
    }

    static uint32_t next_uart_update = 0;
    if (HAL_GetTick() >= next_uart_update)
    {
      adc_measure();
      next_uart_update = HAL_GetTick() + 200;
      fan_update();
    }
    /* USER CODE END WHILE */

    /* USER CODE BEGIN 3 */
  }
  /* USER CODE END 3 */
}

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
/* USER CODE BEGIN 4 */
void HAL_TIM_PeriodElapsedCallback(TIM_HandleTypeDef *htim)
{
  if (htim == &htim3)
  {
    uart_transmit();
  }
}
/* USER CODE END 4 */
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


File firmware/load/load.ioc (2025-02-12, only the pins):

Mcu.UserName=STM32F103C8Tx
PA0-WKUP.Signal=ADCx_IN0
PA13.Signal=SYS_JTMS-SWDIO
PA14.Signal=SYS_JTCK-SWCLK
PA7.GPIO_Label=LED_RED
PA7.Signal=GPIO_Output
PA8.GPIO_Label=FAN
PA8.Signal=S_TIM1_CH1
PB0.GPIO_Label=LED_GREEN
PB0.Signal=GPIO_Output
PB1.GPIO_Label=ADC_ALERT
PB1.Signal=GPXTI1
PB10.GPIO_Label=PERIPHERIAL_SCL
PB10.Signal=I2C2_SCL
PB11.GPIO_Label=PERIPHERIAL_SDA
PB11.Signal=I2C2_SDA
PB15.GPIO_Label=ENABLE_LOAD
PB15.Signal=GPIO_Output
PB3.Signal=SYS_JTDO-TRACESWO
PB6.Signal=USART1_TX
PB7.Signal=USART1_RX
PC13-TAMPER-RTC.GPIO_Label=EXTERNAL_TRIGGER_OUT
PC13-TAMPER-RTC.Signal=GPIO_Output
PC14-OSC32_IN.GPIO_Label=EXTERNAL_TRIGGER_IN
PC14-OSC32_IN.Signal=GPIO_Output
PD0-OSC_IN.Signal=RCC_OSC_IN
PD1-OSC_OUT.Signal=RCC_OSC_OUT

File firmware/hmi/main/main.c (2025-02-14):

#include "freertos/FreeRTOS.h"

#include "utils.h"

#include "bus/spi.h"
#include "bus/uart.h"

#include "control/load.h"
#include "control/menu.h"
#include "control/stream.h"

#include "peripherals/buttons.h"
#include "peripherals/encoder.h"
#include "peripherals/lcd.h"
#include "peripherals/led.h"
#include "peripherals/sd.h"

#include "server/server.h"

#include "ui/index.h"
#include "ui/menu.h"
#include "ui/stream.h"

/** Definitions */
#define MODULE_NAME "main"

void app_main(void)
{
  LOG_PROLOG

  spi_init();

  /** Board peripherals initialization */
  led_init();
  buttons_init();
  encoder_init();
  lcd_init();

  /** Load all UIs */
  ui_index_window();
  ui_menu_window();
  ui_stream_window();

  /** Control initialization */
  load_init();
  menu_init();
  stream_init();

  /** Activate uart by end since it starts communication with load */
  uart_init();

  while (1) {
    vTaskDelay(500 / portTICK_PERIOD_MS);
  }

  LOG_EPILOG
}

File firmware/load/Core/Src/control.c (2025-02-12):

#include <stdio.h>
#include "control.h"
#include "adc.h"
#include "main.h"
#include "server.h"


/* Prototypes */
static void pid_init(pid_controller_t *pid, float kp, float ki, float kd, float control_frequency, boundary_t integral_boundary, boundary_t output_boundary);
static float pid_update(pid_controller_t *pid, control_io_t *io);
static void control_enable_load(uint8_t enable);

static void pid_init(pid_controller_t *pid, float kp, float ki, float kd, float control_frequency, boundary_t integral_boundary, boundary_t output_boundary)
{
	pid->kp = kp;
	pid->ki = ki;
	pid->kd = kd;
	pid->control_frequency = control_frequency;

	/* Initialize internal variables */
	pid->integral = 0.0;

	for (int i = 0; i < 3; ++i)
	{
		pid->error_history[i] = 0.0;
		pid->output_history[i] = 0.0;
	}

	pid->history_index = 0;

	pid->integral_boundary = integral_boundary;

	pid->output_boundary = output_boundary;
}

/**
 * @brief PID controller update function
 * @param pid PID controller instance
 * @param io Control input/output structure
 * @return float controller output
 */
static float pid_update(pid_controller_t *pid, control_io_t *io)
{
	const float error = io->setpoint - io->measured_value;
	const float proportional = pid->kp * error;

	/* If kistory[0] and error have different signs, reset integral term */
	if (pid->error_history[0] * error < 0)
	{
		pid->integral = 0.0;

		for (int i = 0; i < 3; ++i)
		{
			pid->error_history[i] = 0.0;
			pid->output_history[i] = 0.0;
		}
	}

	/* Integral term */
	pid->integral += pid->ki * ((pid->error_history[0] + error) / 2.0) * (1.0 / pid->control_frequency);

	/* Integral boundary */
	if (pid->integral > pid->integral_boundary.max)
		pid->integral = pid->integral_boundary.max;
	else if (pid->integral < pid->integral_boundary.min)
		pid->integral = pid->integral_boundary.min;

	/* Derivative term */
	const float derivative = pid->kd * (2.0 * error - pid->error_history[0] - pid->error_history[1]);

	/* Store error history */
	pid->error_history[2] = pid->error_history[1];
	pid->error_history[1] = pid->error_history[0];
	pid->error_history[0] = error;

	/* Control action */
	float output = proportional + pid->integral + derivative;

	return output;
}

/**
 * @brief Initialize control module
 * @param dac DAC handler
 * @return HAL status
 */
HAL_StatusTypeDef control_init(control_t *control_handler, mcp4725_t *dac)
{
	control_handler->dac = dac;
	const boundary_t integral_boundary = {
		.max = 0.03f,
		.min = -0.03f,
	};

	const float control_frequency = 133.0f;

	/* Initialize constant voltage PID controller */
	pid_init(
		&control_handler->pid[CONTROL_MODE_CV],
		-0.00001f,
		-0.00004f,
		-0.00023f,
		control_frequency,
		(boundary_t){
			.min = -3.00f,
			.max = 3.01f
		},
		(boundary_t){
			.min = 0.0f,
			.max = 3.3f
		}
	);

	/* Initialize constant current PID controller */
	pid_init(
		&control_handler->pid[CONTROL_MODE_CC],
		0.008f,
		0.00f,
		0.0f,
		control_frequency,
		integral_boundary,
		(boundary_t){
			.min = -0.3f,
			.max = 0.3f
		}
	);

	/* Initialize constant power PID controller */
	pid_init(
		&control_handler->pid[CONTROL_MODE_CP],
		0.0f,
		0.0f,
		0.0f,
		control_frequency,
		integral_boundary,
		(boundary_t){
			.min = 0.0f,
			.max = 3.3f
		}
	);

	/* Initialize constant resistance PID controller */
	pid_init(
		&control_handler->pid[CONTROL_MODE_CR],
		-0.1f,
		0.0f,
		0.0f,
		control_frequency,
		integral_boundary,
		(boundary_t){
			.min = 0.0f,
			.max = 3.3f
		}
	);

	control_handler->mode = CONTROL_MODE_CP;

	/* Initialize control IO */
	for (uint32_t i = 0; i < CONTROL_MODE_SIZE; ++i)
	{
		control_set_setpoint(control_handler, i, 0.0f);
		control_handler->io[i].measured_value = 0.0f;
		control_handler->io[i].control_action = 0.0f;
	}
	return HAL_OK;
}

/**
 * @brief Update control module
 */
void control_update(control_t *control_handler)
{
	control_handler->io[CONTROL_MODE_CC].measured_value = adc_get_value(ADC_INPUT_CURRENT);
	control_handler->io[CONTROL_MODE_CV].measured_value = adc_get_value(ADC_INPUT_VOLTAGE);
	control_handler->io[CONTROL_MODE_CP].measured_value = adc_get_value(ADC_INPUT_VOLTAGE) * adc_get_value(ADC_INPUT_CURRENT);
	control_handler->io[CONTROL_MODE_CR].measured_value = adc_get_value(ADC_INPUT_VOLTAGE) / adc_get_value(ADC_INPUT_CURRENT);

	if (control_handler->mode == CONTROL_MODE_CP)
	{

		static float last_current_voltage = 0.0f;

		float current_power_error = control_handler->io[CONTROL_MODE_CP].setpoint - control_handler->io[CONTROL_MODE_CP].measured_value;
		float current_voltage_derivative = control_handler->io[CONTROL_MODE_CV].measured_value - last_current_voltage;
		last_current_voltage = control_handler->io[CONTROL_MODE_CV].measured_value;

		if (current_power_error > 0.0f)
		{
			if (current_voltage_derivative <= 0.0f)
			{
				control_handler->pid[CONTROL_MODE_CP].kp = -0.005f;
				control_handler->pid[CONTROL_MODE_CP].ki = 0.0f;
				control_handler->pid[CONTROL_MODE_CP].kd = 0.0f;
			} else 
			{
				control_handler->pid[CONTROL_MODE_CP].kp = 0.005f;
				control_handler->pid[CONTROL_MODE_CP].ki = 0.0f;
				control_handler->pid[CONTROL_MODE_CP].kd = 0.0f;
			}
		} else
		{
			control_handler->pid[CONTROL_MODE_CP].kp = 0.005f;
			control_handler->pid[CONTROL_MODE_CP].ki = 0.0f;
			control_handler->pid[CONTROL_MODE_CP].kd = 0.0f;
		}
	}
	
	control_handler->io[control_handler->mode].control_action += 
		pid_update(&control_handler->pid[control_handler->mode], &control_handler->io[control_handler->mode]);
	

	
	/* Check if control action is not out of bounds */
	if (control_handler->io[control_handler->mode].control_action > control_handler->pid[control_handler->mode].output_boundary.max)
	{
		control_handler->io[control_handler->mode].control_action = control_handler->pid[control_handler->mode].output_boundary.max;
	}
	else if (control_handler->io[control_handler->mode].control_action < control_handler->pid[control_handler->mode].output_boundary.min)
	{
		control_handler->io[control_handler->mode].control_action = control_handler->pid[control_handler->mode].output_boundary.min;
	}

	float analog_setpoint = 0.0f;

	/* Calculate analog setpoint */
	analog_setpoint = control_handler->io[control_handler->mode].control_action;

	/* Analog controller setpoint is controlled for the calculated setpoint + digital control action */
	if (control_handler->mode == CONTROL_MODE_CC)
	{
		float calculated_analog_setpoint = control_handler->io[CONTROL_MODE_CC].setpoint * 0.08906093f + 0.00743f;
		analog_setpoint = calculated_analog_setpoint + control_handler->io[CONTROL_MODE_CC].control_action;
	}

	mcp4725_set_voltage(control_handler->dac, 3.3f, analog_setpoint, false);

}


static void control_enable_load(uint8_t enable)
{
	HAL_GPIO_WritePin(ENABLE_LOAD_GPIO_Port, ENABLE_LOAD_Pin, enable);
}
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

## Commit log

2024-10-15 .gitignore: Added kicad temp files
2024-10-18 feat(load): Added sensors and control simulation
2024-10-18 feat(load): Added kicad components library
2024-10-18 feat(load): Added base schematic and layout
    [analog.kicad_sch, driver.kicad_sch, load.kicad_pcb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]
2024-10-18 feat(load): route logic and optmize layout
    [driver.kicad_sch, load.kicad_pcb, load.kicad_sch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]
2024-10-18 hardware: pannel: Added first version of HMI
    [display.kicad_sch, esp32.kicad_sch, front_panel.kicad_sch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]
2024-10-20 hardware: panel: Small pins and plane adjustments
    * Adjusted pins for sockets to be bigger
    * Regenerated gnp plane
    [main.kicad_pcb]
2024-10-20 feat(load): finzalize power routing and add mounting holes
    [load.kicad_pcb, load.kicad_sch]
2024-10-20 feat(load): fix DRC errors and warinigs
    [analog.kicad_sch, load.kicad_pcb, power.kicad_sch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]
2024-10-20 hadrware: panel: Rename to Human Machine Interface
    [display.kicad_sch, esp32.kicad_sch, front_panel.kicad_sch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]
2024-10-22 firmware: Add POCs with ESP32 examples for free RTOS
2024-10-22 fix: conect DC pin and change reset to avoid conflicts with UART
    [display.kicad_sch, esp32.kicad_sch, main.kicad_pcb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]
2024-11-06 feat(load): add load base firmware
    [stm32f1x.cfg]
2024-11-27 feat(load): modify analog PID values on the schematic
    [driver.kicad_sch, load.kicad_pcb, load.kicad_sch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]
2024-11-27 feat(load): modify analog PID values on the simulation
2024-11-27 feat(docs): create docs of analog PID tunning
2024-12-01 feat: add adc auto range and average logic
2024-12-01 feat: add uart parser logic
2024-12-01 feat: configure sensor current constants
2024-12-01 feat(uart): implement rx uart parser
2024-12-04 feat: update uart to use generic parser
2024-12-04 hmi: Small fixes on i2c transmission
    [load.c]
2024-12-04 feat(load): get i2c buffer via DMA
2025-02-11 feat: communicate via uart
2025-02-11 hardware: hmi: Change to UART
    [esp32.kicad_sch, main.kicad_pcb]
2025-02-12 load: uart comunication wirking
2025-02-12 docs: add final assembly and panel assembly docs
2025-02-12 docs: add final assembly images

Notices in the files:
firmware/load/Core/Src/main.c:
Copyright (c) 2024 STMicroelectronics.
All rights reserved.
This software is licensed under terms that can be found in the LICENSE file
